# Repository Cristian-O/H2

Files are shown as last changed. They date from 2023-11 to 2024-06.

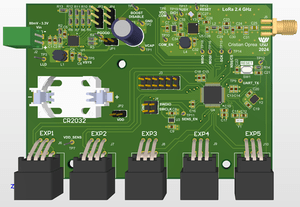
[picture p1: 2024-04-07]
APP/v2/node_design.png

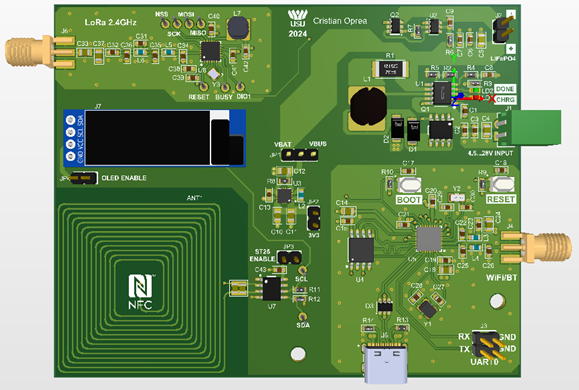
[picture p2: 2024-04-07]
APP/v2/gateway_design.png

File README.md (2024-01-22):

#### 2.4 GHz LoRa Gateway and Node for data aquisition powered by renewable energy

- Node



- Sensor modules
  


- Gateway



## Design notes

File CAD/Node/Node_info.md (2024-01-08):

#Versions
---
## version 1
- [x] SCH_Library
- [x] Schematic
- [ ] PCB_Library
- [ ] Rules
- [ ] Layout
- [ ] Review
- [ ] Enclosure
- [ ] Manufacturing Files
- [ ] Production
> concept version (only schematic)
## version 2
- [x] SCH_Library
- [x] Schematic
- [x] PCB_Library
- [x] Rules
- [x] Layout
- [ ] Review
- [ ] Enclosure
- [ ] Manufacturing Files
- [ ] Production

> *PCB layout and rules for JLCPCB manufacturing added as well as jumpers for current measurement*
Screenshot 2023-11-08 _top
Screenshot 2023-11-08 _bottom
## version 3
- [x] SCH_Library
- [x] Schematic
- [x] PCB_Library
- [x] Rules
- [x] Layout
- [x] Review
- [ ] Enclosure
- [x] Manufacturing Files
- [x] Production
> improved PCB layout, mounting, legends and ADP5091 REG_Dx select jumper (LDO/BOOST enable), calculated capacitors for crystals (16pF), reduced BOM (R and C for reset button)
ready for manufacturing (manufactured in dececmber 2023)
---

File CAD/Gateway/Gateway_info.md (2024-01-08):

#Versions
---
## version 1
- [x] SCH_Library
- [x] Schematic
- [ ] PCB_Library
- [ ] Rules
- [ ] Layout
- [ ] Review
- [ ] Enclosure
- [ ] Manufacturing Files
- [ ] Production
> concept version (only schematic)
## version 2
- [x] SCH_Library
- [x] Schematic
- [x] PCB_Library
- [x] Rules
- [x] Layout
- [ ] Review
- [ ] Enclosure
- [ ] Manufacturing Files
- [ ] Production

> *PCB layout and rules for JLCPCB manufacturing added as well as jumpers for current measurement*



## version 3
- [x] SCH_Library
- [x] Schematic
- [x] PCB_Library
- [x] Rules
- [x] Layout
- [ ] Review
- [ ] Enclosure
- [ ] Manufacturing Files
- [ ] Production
> added legends

## version 4
- [x] SCH_Library
- [x] Schematic
- [x] PCB_Library
- [x] Rules
- [x] Layout
- [x] Review
- [x] Enclosure
- [x] Manufacturing Files
- [x] Production
> modified NOR flash footprint (SOIC-8 208mil), length tuning on tracks
ready for manufacturing (manufactured in december 2023)
---

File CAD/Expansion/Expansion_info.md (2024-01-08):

#Versions
---
## version 1
- [x] SCH_Library
- [x] Schematic
- [x] PCB_Library
- [x] Rules
- [x] Layout
- [ ] Review
- [ ] Manufacturing Files
- [ ] Production
> concept version (only schematic)
## version 2
- [x] SCH_Library
- [x] Schematic
- [x] PCB_Library
- [x] Rules
- [x] Layout
- [ ] Review
- [ ] Manufacturing Files
- [ ] Production
> layout completed




## version 3
- [x] SCH_Library
- [x] Schematic
- [x] PCB_Library
- [x] Rules
- [x] Layout
- [x] Review
- [ ] Manufacturing Files
- [ ] Production
> small improvements
## version 4
- [x] SCH_Library
- [x] Schematic
- [x] PCB_Library
- [x] Rules
- [x] Layout
- [x] Review
- [x] Manufacturing Files
- [x] Production
> ready for production version( manufactured in december 2023)         
---

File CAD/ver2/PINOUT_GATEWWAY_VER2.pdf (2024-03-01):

GPIO

PIN | FUNCTION | CONNECTION
MTCK | MOSI | LoRa
MTDO | MISO | LoRa
MTMS | LoRa_NSS | LoRa
MTDI | SCK | LoRa
U0RXD | UART0_RXD | PROG
U0TXD | UART0_TXD | PROG
GPIO2 | SDA(+FLASH BOOT) | SDA
GPIO3 | DIO1 | LoRa
GPIO8 | SCL(+FLASH BOOT) | SCL
GPIO9 | RESET | LoRa
GPIO10 | BUSY | LoRa
GPIO18 | USB_D_N | PROG
GPIO19 | USB_D_P | PROG

LoRa

MTCK | MOSI | LoRa
MTDO | MISO | LoRa
MTMS | LoRa_NSS | LoRa
MTDI | SCK | LoRa
GPIO3 | DIO1 | LoRa
GPIO9 | RESET(+MCU BOOT) | LoRa
GPIO10 | BUSY | LoRa

PROG

U0RXD | UART0_RXD | PROG
U0TXD | UART0_TXD | PROG
GPIO18 | USB_D_N | PROG
GPIO19 | USB_D_P | PROG

I2C (OLED+ST25DV)

GPIO2 | SDA(+FLASH BOOT) | SDA
GPIO8 | SCL(+FLASH BOOT) | SCL

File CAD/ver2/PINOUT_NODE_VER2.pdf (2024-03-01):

Expansion

PIN | FUNCTION | CONNECTOR
PA4 | ADC12_IN9, DAC1_OUT2 | EXP1
PB10 | I2C2_SCL, TIM2_CH3, USART3_TX, LPUART1_RX | EXP1
PB11 | I2C2_SDA, TIM2_CH4, USART3_RX LPUART1_TX | EXP1
PA0 | ADC1_IN5, WKUP1 | EXP2
PA9 | I2C1_SCL, TIM1_CH2, USART1_TX | EXP2
PA10 | I2C1_SDA, TIM1_CH3, USART1_RX | EXP2
PA1 | ADC1_IN6 | EXP3
PB6 | I2C1_SCL, TIM16_CH1N, USART1_TX | EXP3
PB7 | I2C1_SDA, USART1_RX | EXP3
PA5 | ADC1_IN10, DAC1_OUT2 | EXP4
PB13 | I2C2_SCL, TIM1_CH1N | EXP4
PB14 | I2C2_SDA, TIM15_CH1 | EXP4
PA3 | ADC12_IN7 | EXP5
PB8 | I2C1_SCL, TIM16_CH1 | EXP5
PB9 | I2C1_SDA | EXP5

GPIO-Expansion

PIN | FUNCTION | CONNECTION
PA2 | UART | UART_TX
PA6 | MISO/TX | LoRa
PA7 | MOSI/RX | LoRa
PA8 | COM_EN | LoRa(TPS22919)
PA11 | RESET | LoRa
PA12 | DIO1 | LoRa
PA13 | SWDIO | PROG
PA14 | SWCLK | PROG
PA15 | NSS_CTS | LoRa
PC13 | ADC/NOT_USED | NOT_USED
NRST | RESET+TP12 | PROG
PB0 | BUSY | LoRa
PB1 | BOOST_DISABLE | ADP5091
PB2 | LLD | ADP5091
PB3 | SCK_RTS | LoRa
PB4 | NOT_USED | NOT_USED
PB5 | NOT_USED | NOT_USED
PB12 | NOT_USED | NOT_USED
PB15 | SENS_EN | Sensors(TPS22919)

LoRa

PIN | FUNCTION | CONNECTION
PA6 | MISO/TX | LoRa
PA7 | MOSI/RX | LoRa
PA8 | COM_EN | LoRa(TPS22919)
PA11 | RESET | LoRa
PA12 | DIO1 | LoRa
PA15 | NSS_CTS | LoRa
PB0 | BUSY | LoRa
PB3 | SCK_RTS | LoRa

ADP5091

PB1 | BOOST_DISABLE | ADP5091
PB2 | LLD | ADP5091

PROG+DEBUG

PA13 | SWDIO (SWD) | PROG
PA14 | SWCLK (SWD) | PROG
NRST | RESET(TP12) (SWD HARD RESET) | PROG
PA2 | UART | UART_TX

NOT USED

PC13 | ADC/NOT_USED | NOT_USED
PB4 | NOT_USED | NOT_USED
PB5 | NOT_USED | NOT_USED
PB12 | NOT_USED | NOT_USED

ENABLE

PA8 | COM_EN | LoRa(TPS22919)
PB15 | SENS_EN | Sensors

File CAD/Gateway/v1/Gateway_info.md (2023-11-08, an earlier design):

#Versions
---
## version 1
- [x] SCH_Library
- [x] Schematic
- [ ] Antenna Footprint
- [ ] PCB_Library
- [ ] Rules
- [ ] Layout
- [ ] Modules: Schematic and Layout
- [ ] Review
- [ ] Enclosure
- [ ] Manufacturing Files
- [ ] Production
> concept version (only schematic)
## version 2
- [x] SCH_Library
- [x] Schematic
- [ ] Antenna Footprint
- [ ] PCB_Library
- [ ] Rules
- [ ] Layout
- [ ] Modules: Schematic and Layout
- [ ] Review
- [ ] Enclosure
- [ ] Manufacturing Files
- [ ] Production
---

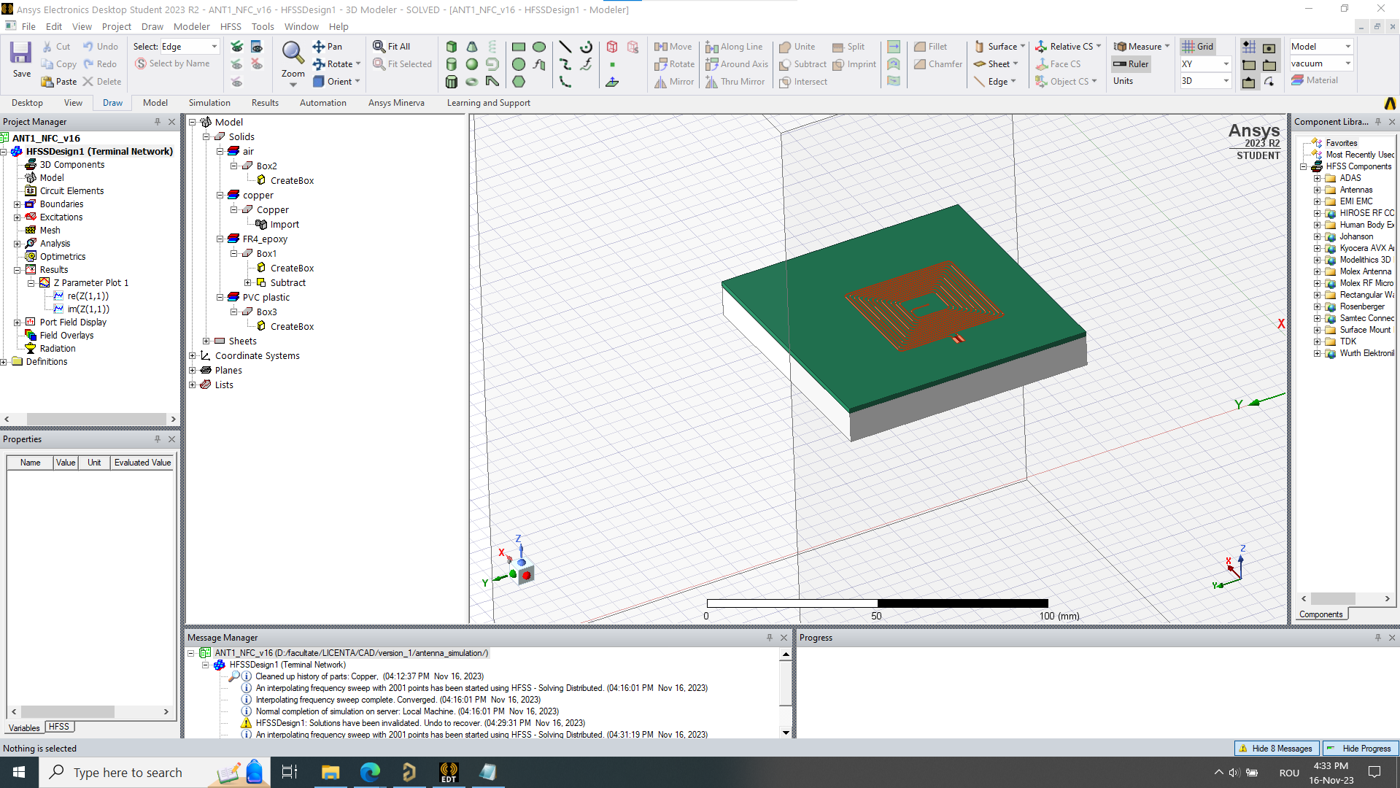
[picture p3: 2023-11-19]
Simulation/NFC_Antenna/ant_v16_design_PVC_10mm.png

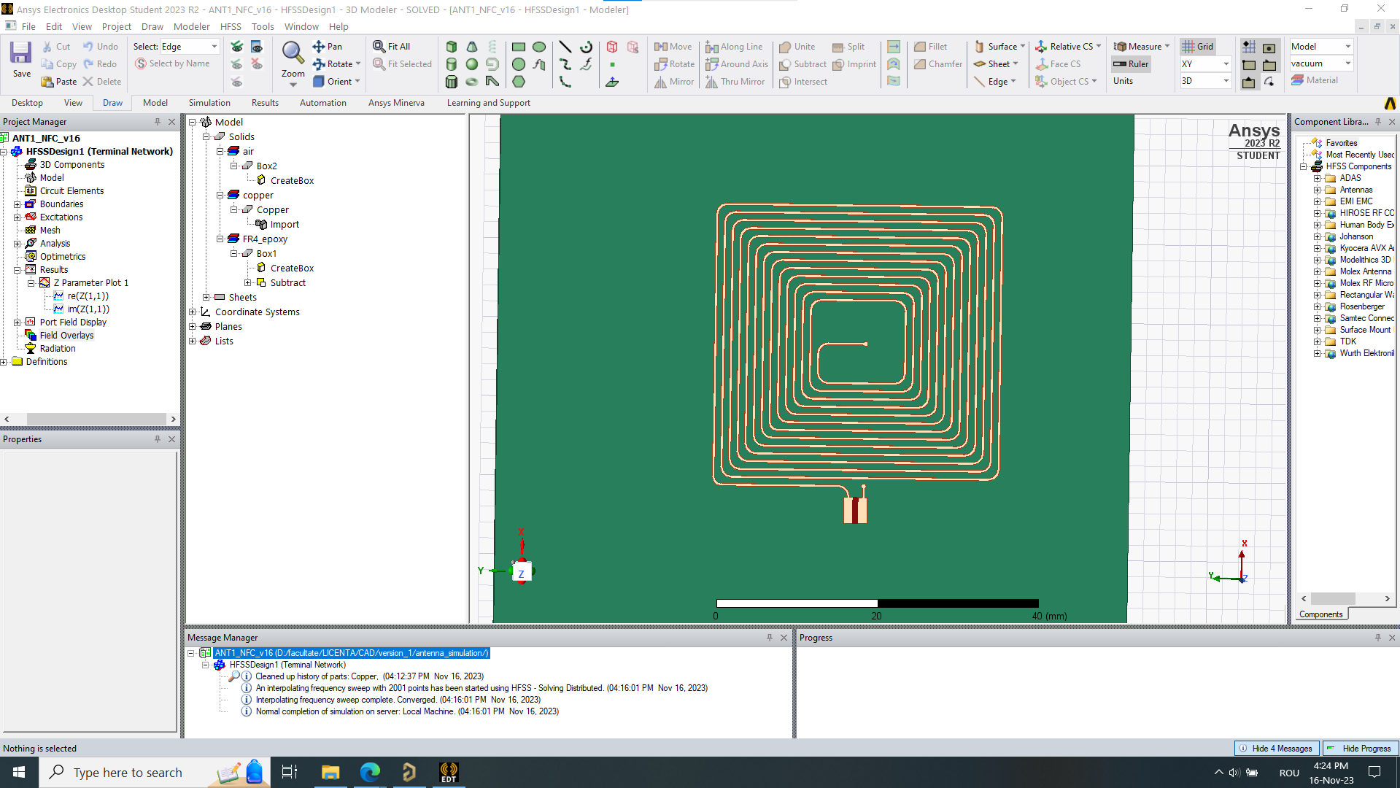
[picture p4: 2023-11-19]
Simulation/NFC_Antenna/ant_v16_design.png

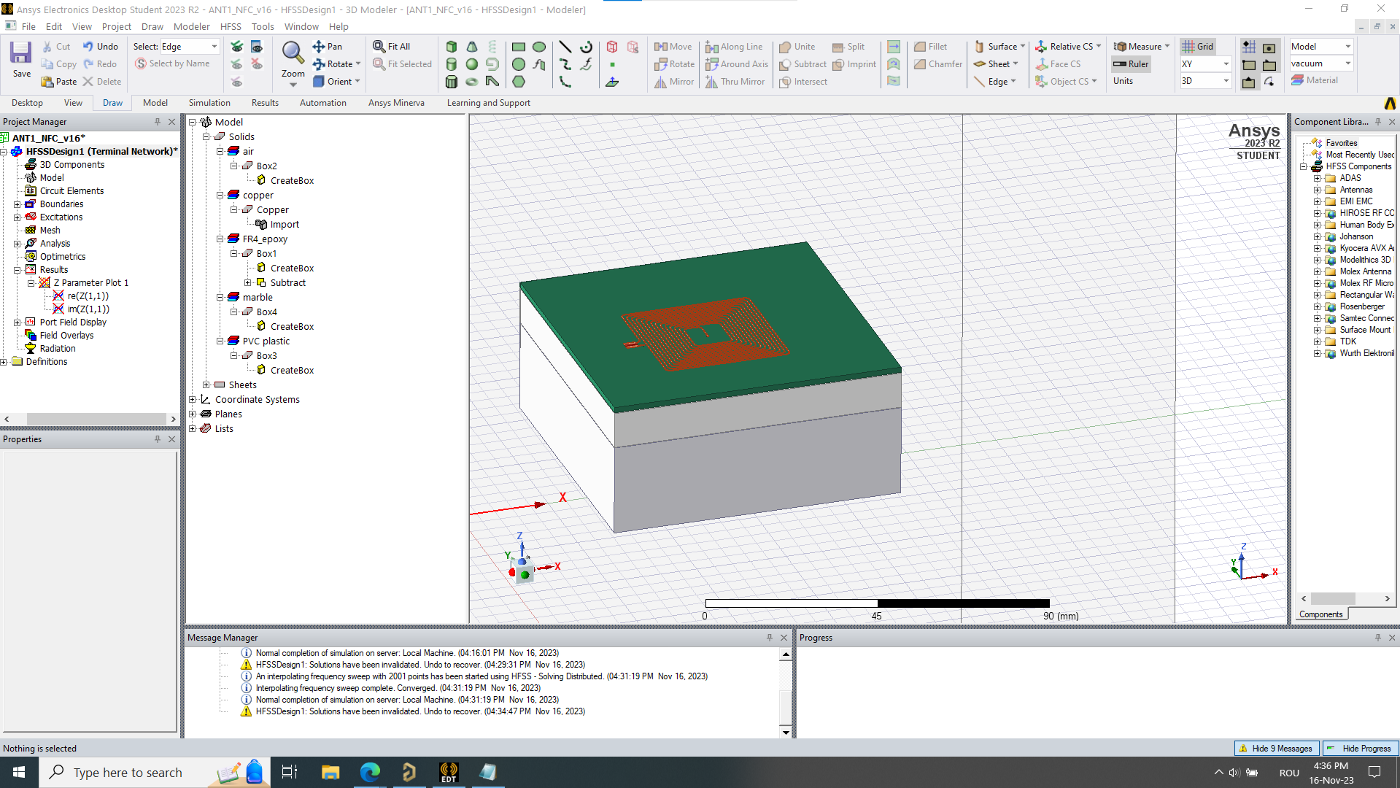
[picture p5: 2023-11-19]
Simulation/NFC_Antenna/ant_v16_design_PVC_10mm_marble_25mm.png

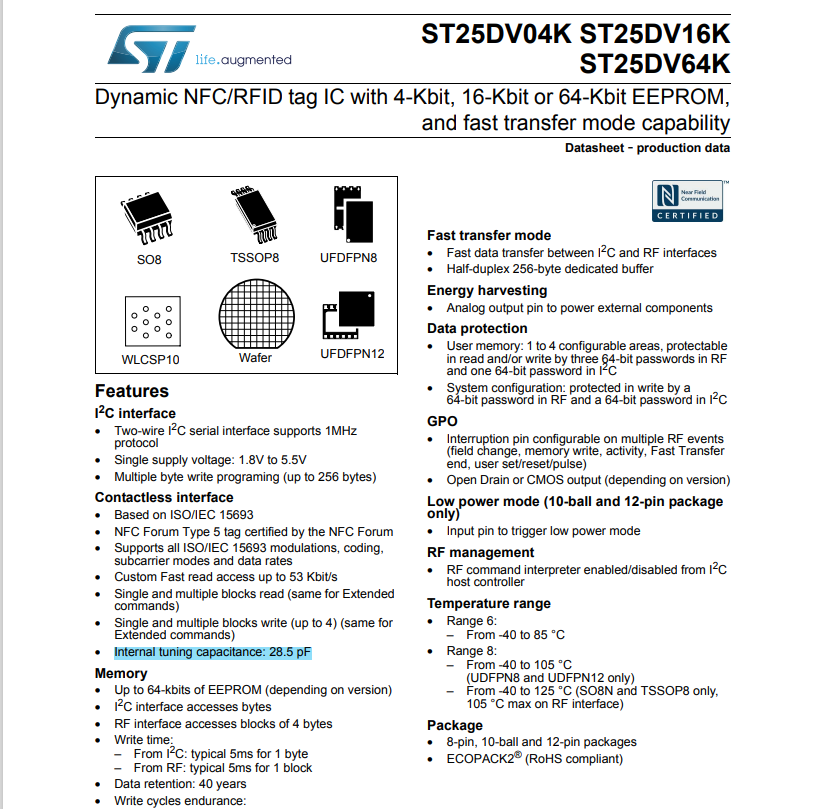
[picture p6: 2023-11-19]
Simulation/NFC_Antenna/ST25DVxx_internal_capacitor.png

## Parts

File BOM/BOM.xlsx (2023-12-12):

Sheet: BOM
PN | Cantitate | Pret | Descriere | Categorie | Total | Subtotal
Condensatori
CL10B104KB8NNNC (https://www.lcsc.com/product-detail/Multilayer-Ceramic-Capacitors-MLCC-SMD-SMT_Samsung-Electro-Mechanics-CL10B104KB8NNNC_C1591.html) | 100 | 0.0025 | 100nF 0603 | Cap | 0.25
CC0603KRX7R9BB103 (https://www.lcsc.com/product-detail/Multilayer-Ceramic-Capacitors-MLCC-SMD-SMT_YAGEO-CC0603KRX7R9BB103_C100042.html) | 100 | 0.002 | 10nF 0603 | Cap | 0.2
CL10A106MP8NNNC (https://www.lcsc.com/product-detail/Multilayer-Ceramic-Capacitors-MLCC-SMD-SMT_Samsung-Electro-Mechanics-CL10A106MP8NNNC_C85713.html) | 100 | 0.0054 | 10uF 0603 | Cap | 0.54
CL21A106KAYNNNE (https://www.lcsc.com/product-detail/Multilayer-Ceramic-Capacitors-MLCC-SMD-SMT_Samsung-Electro-Mechanics-CL21A106KAYNNNE_C15850.html) | 50 | 0.0105 | 10uF 0805 | Cap | 0.525
CL10A475KA8NQNC (https://www.lcsc.com/product-detail/Multilayer-Ceramic-Capacitors-MLCC-SMD-SMT_Samsung-Electro-Mechanics-CL10A475KA8NQNC_C69335.html) | 50 | 0.0145 | 4.7uF 0603 | Cap | 0.725
CL10A105KO8NNNC (https://www.lcsc.com/product-detail/Multilayer-Ceramic-Capacitors-MLCC-SMD-SMT_Samsung-Electro-Mechanics-CL10A105KO8NNNC_C1592.html) | 100 | 0.0031 | 1uF 0603 | Cap | 0.31
0603CG1R2C500NT (https://www.lcsc.com/product-detail/Multilayer-Ceramic-Capacitors-MLCC-SMD-SMT_FH-Guangdong-Fenghua-Advanced-Tech-0603CG1R2C500NT_C1638.html) | 100 | 0.0029 | 1.2pF 0603 | Cap | 0.29
TCC0603X5R474M250CT (https://www.lcsc.com/product-detail/Multilayer-Ceramic-Capacitors-MLCC-SMD-SMT_CCTC-TCC0603X5R474M250CT_C18185762.html) | 100 | 0.0038 | 470nF 0603 | Cap | 0.38
FCC0603N0R5C500CT (https://www.lcsc.com/product-detail/Multilayer-Ceramic-Capacitors-MLCC-SMD-SMT_FOJAN-FCC0603N0R5C500CT_C5137584.html) | 100 | 0.0031 | 0.5pF 0603 | Cap | 0.31
CL10C101JB8NNNC (https://www.lcsc.com/product-detail/Multilayer-Ceramic-Capacitors-MLCC-SMD-SMT_Samsung-Electro-Mechanics-CL10C101JB8NNNC_C14858.html) | 100 | 0.0027 | 100pF 0603 | Cap | 0.27
0603CG0R8C500NT (https://www.lcsc.com/product-detail/Multilayer-Ceramic-Capacitors-MLCC-SMD-SMT_FH-Guangdong-Fenghua-Advanced-Tech-0603CG0R8C500NT_C501845.html) | 100 | 0.003 | 0.8pF 0603 | Cap | 0.3
CL10B224KA8NNNC (https://www.lcsc.com/product-detail/Multilayer-Ceramic-Capacitors-MLCC-SMD-SMT_Samsung-Electro-Mechanics-CL10B224KA8NNNC_C21120.html) | 100 | 0.0057 | 220nF 0603 | Cap | 0.57
0603CG3R3C500NT (https://www.lcsc.com/product-detail/Multilayer-Ceramic-Capacitors-MLCC-SMD-SMT_FH-Guangdong-Fenghua-Advanced-Tech-0603CG3R3C500NT_C1660.html) | 100 | 0.0027 | 3.3pF 0603 | Cap | 0.27
0603CG160J500NT (https://www.lcsc.com/product-detail/Multilayer-Ceramic-Capacitors-MLCC-SMD-SMT_FH-Guangdong-Fenghua-Advanced-Tech-0603CG160J500NT_C1646.html) | 100 | 0.0039 | 16pF, C0G, 0603 | Cap | 0.39
 |  |  |  |  |  | 5.33
Rezistori
RS-03K5101FT (https://www.lcsc.com/product-detail/Chip-Resistor-Surface-Mount_FH-Guangdong-Fenghua-Advanced-Tech-RS-03K5101FT_C156350.html) | 100 | 0.001 | 5.1k 0603 | Rez | 0.1
RC0603FR-071K5L (https://www.lcsc.com/product-detail/Chip-Resistor-Surface-Mount_YAGEO-RC0603FR-071K5L_C114668.html) | 100 | 0.0012 | 1.5k 0603 | Rez | 0.12
0603WAF1000T5E (https://www.lcsc.com/product-detail/Chip-Resistor-Surface-Mount_UNI-ROYAL-Uniroyal-Elec-0603WAF1000T5E_C22775.html) | 100 | 0.001 | 100R 0603 | Rez | 0.1
PT2512FK-7W0R25L (https://www.lcsc.com/product-detail/Chip-Resistor-Surface-Mount_YAGEO-PT2512FK-7W0R25L_C875877.html) | 5 | 0.1434 | 250mR 2512 | Rez | 0.717
FRC0603F1200TS (https://www.lcsc.com/product-detail/Chip-Resistor-Surface-Mount_FOJAN-FRC0603F1200TS_C2906988.html) | 100 | 0.0009 | 120R 0603 | Rez | 0.09
SCR0603F27K (https://www.lcsc.com/product-detail/Chip-Resistor-Surface-Mount_VO-SCR0603F27K_C3016359.html) | 100 | 0.0009 | 27k 0603 | Rez | 0.09
RTT033001FTP (https://www.lcsc.com/product-detail/Chip-Resistor-Surface-Mount_RALEC-RTT033001FTP_C103514.html) | 100 | 0.0008 | 3k 0603 | Rez | 0.08
RS-03K2001FT (https://www.lcsc.com/product-detail/Chip-Resistor-Surface-Mount_FH-Guangdong-Fenghua-Advanced-Tech-RS-03K2001FT_C115336.html) | 100 | 0.001 | 2k 0603 | Rez | 0.1
WR04W6044FTL (https://www.lcsc.com/product-detail/Chip-Resistor-Surface-Mount_Walsin-Tech-Corp-WR04W6044FTL_C172106.html) | 50 | 0.0012 | 6.04M 0402 (nu e 0603) | Rez | 0.06
RC0603FR-074M7L (https://www.lcsc.com/product-detail/Chip-Resistor-Surface-Mount_YAGEO-RC0603FR-074M7L_C123423.html) | 100 | 0.0012 | 4.7M 0603 | Rez | 0.12
SCR0603J18M (https://www.lcsc.com/product-detail/Chip-Resistor-Surface-Mount_VO-SCR0603J18M_C3017646.html) | 100 | 0.0013 | 18M 0603 | Rez | 0.13
FRC0603F2213TS (https://www.lcsc.com/product-detail/Chip-Resistor-Surface-Mount_FOJAN-FRC0603F2213TS_C7467463.html) | 100 | 0.0008 | 221kR 0603 | Rez | 0.08
RC0603FR-07150KL (https://www.lcsc.com/product-detail/Chip-Resistor-Surface-Mount_YAGEO-RC0603FR-07150KL_C114660.html) | 100 | 0.0012 | 150k 0603 | Rez | 0.12
WR06X4701FTL (https://www.lcsc.com/product-detail/Chip-Resistor-Surface-Mount_Walsin-Tech-Corp-WR06X4701FTL_C163914.html) | 100 | 0.0009 | 4.7k 0603 | Rez | 0.09
RC0402FR-075M9L (https://www.lcsc.com/product-detail/Chip-Resistor-Surface-Mount_YAGEO-RC0402FR-075M9L_C477757.html) | 100 | 0.0007 | 5.9M 0603 | Rez | 0.07
WR06W4124FTL (https://www.lcsc.com/product-detail/Chip-Resistor-Surface-Mount_Walsin-Tech-Corp-WR06W4124FTL_C367755.html) | 100 | 0.0017 | 4.12M 0603 | Rez | 0.17
RC0402FR-075M49L (https://www.lcsc.com/product-detail/Chip-Resistor-Surface-Mount_YAGEO-RC0402FR-075M49L_C477751.html) | 100 | 0.0007 | 5.49M 0402 | Rez | 0.07
RC0603FR-074M53L (https://www.lcsc.com/product-detail/Chip-Resistor-Surface-Mount_YAGEO-RC0603FR-074M53L_C482860.html) | 100 | 0.0012 | 4.53M 0603 | Rez | 0.12
RC0402FR-073M92L (https://www.lcsc.com/product-detail/Chip-Resistor-Surface-Mount_YAGEO-RC0402FR-073M92L_C477709.html) | 100 | 0.001 | 3.92M 0402 | Rez | 0.1
WR06X1003FTL (https://www.lcsc.com/product-detail/Chip-Resistor-Surface-Mount_Walsin-Tech-Corp-WR06X1003FTL_C132374.html) | 100 | 0.0009 | 100k 0603 | Rez | 0.09
RC0603FR-0733K2L (https://www.lcsc.com/product-detail/Chip-Resistor-Surface-Mount_YAGEO-RC0603FR-0733K2L_C185338.html) | 100 | 0.0012 | 33.2k 0603 | Rez | 0.12
 |  |  |  |  |  | 2.737
Bobine
XRCD75-470M (https://www.lcsc.com/product-detail/Power-Inductors_XR-XRCD75-470M_C5289449.html) | 5 | 0.0689 | 47uH, 5x7 | Bobine | 0.3445
CPY160808T-2R2M-NP (https://www.lcsc.com/product-detail/Inductors-SMD_Chilisin-Elec-CPY160808T-2R2M-NP_C365953.html) | 20 | 0.0138 | 2,2uH, 0603 | Bobine | 0.276
SDCL1608C2N4STDF (https://www.lcsc.com/product-detail/Inductors-SMD_Sunlord-SDCL1608C2N4STDF_C370235.html) | 50 | 0.0084 | 2,4nH, 0603 | Bobine | 0.42
VHF160808H3N0ST (https://www.lcsc.com/product-detail/Inductors-SMD_FH-Guangdong-Fenghua-Advanced-Tech-VHF160808H3N0ST_C395085.html) | 100 | 0.0054 | 3nH, 0603 | Bobine | 0.54 |  | 2.5 nu e in stoc => 2.4 utilizat
XRCD43-220M (https://www.lcsc.com/product-detail/Power-Inductors_span-style-background-color-ff0-XR-span-XRCD43-220M_C5289404.html) | 20 | 0.0266 | 22uH, 4x3.2 | Bobine | 0.532
XRCD43-150M (https://www.lcsc.com/product-detail/Power-Inductors_span-style-background-color-ff0-XR-span-XRCD43-150M_C5289403.html) | 20 | 0.0266 | 15uH, 4x3.2 | Bobine | 0.532
VHF160808H2N2ST (https://www.lcsc.com/product-detail/Inductors-SMD_FH-Guangdong-Fenghua-Advanced-Tech-VHF160808H2N2ST_C1028.html) | 100 | 0.0055 | 2.2nH 0603 | Bobine | 0.55
CH1608H6N8J(f) (https://www.lcsc.com/product-detail/Inductors-SMD_CEC-Shenzhen-Zhenhua-Fu-Elec-CH1608H6N8J-f_C316305.html) | 100 | 0.0036 | 6,8nH 0603 | Bobine | 0.36 | 3.1945
Diode
SS34-MS (https://www.lcsc.com/product-detail/Schottky-Barrier-Diodes-SBD_MSKSEMI-SS34-MS_C2836396.html) | 20 | 0.0196 | Dioda putere | Dioda | 0.392
USBLC6-2SC6 (https://www.lcsc.com/product-detail/ESD-Protection-Devices_UMW-Youtai-Semiconductor-Co-Ltd-USBLC6-2SC6_C2687116.html) | 10 | 0.0341 | ESD USB | Diode ESD | 0.341
XL-1608SURC-06 (https://www.lcsc.com/product-detail/Light-Emitting-Diodes-LED_XINGLIGHT-XL-1608SURC-06_C965799.html) | 100 | 0.0026 | LED 0603 rosu | LED | 0.26
XL-1608SYGC-06 (https://www.lcsc.com/product-detail/Light-Emitting-Diodes-LED_XINGLIGHT-XL-1608SYGC-06_C965805.html) | 100 | 0.0048 | LED 0603 verde | LED | 0.48
 |  |  |  |  |  | 1.473
Cristale cuart
01.X.TG.11CJJRI000327680 (https://www.lcsc.com/product-detail/Crystals_CREC-01-X-TG-11CJJRI000327680_C7570522.html) | 5 | 0.1184 | 32.768kHz, 12.5pF, 3215x2 | Cristal | 0.592
X32258MOB4SI (https://www.lcsc.com/product-detail/Crystals_YXC-X32258MOB4SI_C2682775.html) | 5 | 0.1387 | 8MHz, 12pF, 3225x4 | Cristal | 0.6935
S3240000121040 (https://www.lcsc.com/product-detail/Crystals_JGHC-S3240000121040_C426989.html) | 10 | 0.048 | 40MHz, 12pF,3225x4 | Cristal | 0.48
XC21M4-52.000-F10NNHPL (https://www.lcsc.com/product-detail/Crystals_HCI-XC21M4-52-000-F10NNHPL_C3034316.html) | 5 | 0.1224 | 52MHz, 10pF | Cristal | 0.612
 |  |  |  |  |  | 2.3775
Circuite Integrate
SX1280IMLTRT (https://www.lcsc.com/product-detail/RF-Transceiver-ICs_SEMTECH-SX1280IMLTRT_C125969.html) | 3 | 4.7489 | 2.4 GHz LoRa |  | 14.2467
STM32L431CCT6 (https://www.lcsc.com/product-detail/Microcontroller-Units-MCUs-MPUs-SOCs_STMicroelectronics-STM32L431CCT6_C486681.html) | 2 | 1.8741 | STM32L431, 256 kB, LQFP-48 |  | 3.7482
ADP5091ACPZ-2-R7 (https://www.lcsc.com/product-detail/Battery-Management-ICs_Analog-Devices-ADP5091ACPZ-2-R7_C579259.html) | 2 | 5.1801 | ADP5091, low power energy harvester |  | 10.3602
TPS22919DCKR (https://www.lcsc.com/product-detail/Power-Distribution-Switches_Texas-Instruments-TPS22919DCKR_C2149796.html) | 4 | 0.3389 | power distribution switch |  | 1.3556
CN3801 (https://www.lcsc.com/product-detail/Battery-Management-ICs_ShangHai-Consonance-Elec-CN3801_C840499.html) | 2 | 0.5091 | incarcator LiFePO4 |  | 1.0182
HY2112-BB (https://www.lcsc.com/product-detail/Battery-Management-ICs_HYCON-Tech-HY2112-BB_C161942.html) | 5 | 0.1005 | LiFePO4 protectie |  | 0.5025
ST25DV04K-IER6S3 (https://www.lcsc.com/product-detail/RF-Chips_STMicroelectronics-ST25DV04K-IER6S3_C155601.html) | 3 | 0.3675 | NFC |  | 1.1025
ESP32-C3 (https://www.lcsc.com/product-detail/Microcontroller-Units-MCUs-MPUs-SOCs_Espressif-Systems-ESP32-C3_C2838500.html) | 2 | 1.3539 | uC |  | 2.7078
TPS63000DRCR (https://www.lcsc.com/product-detail/DC-DC-Converters_Texas-Instruments-TPS63000DRCR_C24966.html) | 2 | 0.8846 | DC-DC buck boost |  | 1.7692
W25Q32JVSSIQ (https://www.lcsc.com/product-detail/NOR-FLASH_Winbond-Elec-W25Q32JVSSIQ_C82344.html) | 5 | 0.2616 | NOR flash |  | 1.308
FDS4435BZ(UMW) (https://www.lcsc.com/product-detail/MOSFETs_UMW-Youtai-Semiconductor-Co-Ltd-FDS4435BZ-UMW_C7503191.html) | 5 | 0.1528 | MOS protectie |  | 0.764
FS8205A (https://www.lcsc.com/product-detail/MOSFETs_FUXINSEMI-FS8205A_C908265.html) | 10 | 0.0569 | MOS protectie |  | 0.569
LPV521MGX/NOPB (https://www.lcsc.com/product-detail/Operational-Amplifier_Texas-Instruments-LPV521MGX-NOPB_C779403.html) | 4 | 0.7 | OPAMP |  | 2.8
REF3020AIDBZR (https://www.lcsc.com/product-detail/Voltage-References_Texas-Instruments-REF3020AIDBZR_C26804.html) | 2 | 0.4853 | 2.048V reference series |  | 0.9706
ENS210-LQFM (https://www.lcsc.com/product-detail/Temperature-and-Humidity-Sensor_AMS-ENS210-LQFM_C2991202.html) | 2 | 1.1519 | Temp+Umid |  | 2.3038
LTR-390UV-01 (https://www.lcsc.com/product-detail/Ambient-Light-Sensors_Lite-On-LTR-390UV-01_C492374.html) | 2 | 0.9594 | UV+Nivel Lumina |  | 1.9188
 |  |  |  |  |  | 47.4451
Conectori
12251140CNG0S115001 (https://www.lcsc.com/product-detail/Pin-Headers_JILN-12251140CNG0S115001_C429959.html) | 5 | 0.0962 | 2.54, 40p, drept | Header | 0.481
KH-2.54TXM-BK-6.5H-R (https://www.lcsc.com/product-detail/Shunts-Jumpers_Shenzhen-Kinghelm-Elec-KH-2-54TXM-BK-6-5H-R_C5274540.html) | 50 | 0.0081 | 2.54, inchis, rosu | Jumper | 0.405
M254D-02-065-B (https://www.lcsc.com/product-detail/Shunts-Jumpers_DEALON-M254D-02-065-B_C2998928.html) | 50 | 0.0069 | 2.54, inchis, negru | Jumper | 0.345
ER06BGFBK (https://www.lcsc.com/product-detail/Card-Edge-Connectors_WingTAT-ER06BGFBK_C5173325.html) | 10 | 0.288 | 2,54, 6P, card edge | Conector | 2.88
SKRPACE010 (https://www.lcsc.com/product-detail/Tactile-Switches_ALPSALPINE-SKRPACE010_C139797.html) | 10 | 0.053 | tactile switch, RESET | Buton | 0.53
CR2032-BS-6-1 (https://www.lcsc.com/product-detail/Battery-Connectors_Q-J-CR2032-BS-6-1_C70377.html) | 5 | 0.1559 | CR2032 suport | Conector baterie | 0.7795
BWSMA-KE-P001 (https://www.lcsc.com/product-detail/RF-Connectors-Coaxial-Connectors_BAT-WIRELESS-BWSMA-KE-P001_C496550.html) | 5 | 0.3453 | SMA edge mount | Conector RF | 1.7265
DB2ERC-2.54-2P-GN (https://www.lcsc.com/product-detail/Pluggable-System-Terminal-Block_DORABO-DB2ERC-2-54-2P-GN_C2927503.html) | 5 | 0.073 | Plugin terminal 90* PCB | Conector | 0.365
DB2EK-2.54-2P-GN-S (https://www.lcsc.com/product-detail/Pluggable-System-Terminal-Block_DORABO-DB2EK-2-54-2P-GN-S_C2927483.html) | 5 | 0.3002 | Plugin terminal cablu | Conector | 1.501
TYPE-C 16PIN 2MD(073) (https://www.lcsc.com/product-detail/USB-Connectors_SHOU-HAN-TYPE-C-16PIN-2MD-073_C2765186.html) | 5 | 0.0524 | USB-C | Conector | 0.262
TF-115-BCP9 (https://www.lcsc.com/product-detail/SD-Card-Connectors_XUNPU-TF-115-BCP9_C720505.html) | 5 | 0.074 | uSD card | Conector | 0.37
KH-BNC50-3511 (https://www.lcsc.com/product-detail/RF-Connectors-Coaxial-Connectors_Shenzhen-Kinghelm-Elec-KH-BNC50-3511_C2837587.html) | 1 | 0.6619 | BNC | Conector | 0.6619
MX127-5.0-03P-GN01-Cu-Y-A (https://www.lcsc.com/product-detail/Screw-terminal_MAX-MX127-5-0-03P-GN01-Cu-Y-A_C5188441.html) | 5 | 0.1543 | Terminal Surub 5mm | Conector | 0.7715
 |  |  |  |  |  | 11.0784
 |  |  |  |  | 73.9955

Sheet: Misc
PN | Cantitate | Pret | Descriere | Total
BW2.4JWX105-7KJ (https://www.lcsc.com/product-detail/Antennas_BAT-WIRELESS-BW2-4JWX105-7KJ_C497017.html) | 3 | 1.1087 | Antena 2.4 GHz pentru WiFi sau LoRa | 3.3261
KH-SMA-K513-11G (https://www.lcsc.com/product-detail/RF-Connectors-Coaxial-Connectors_Shenzhen-Kinghelm-Elec-KH-SMA-K513-11G_C530660.html) | 4 | 0.5091 | Conector SMA cu surub pentru antena | 2.0364
DOSIN-811-0211A (https://www.lcsc.com/product-detail/Radio-Frequency-Cable_dosinconn-DOSIN-811-0211A_C3018934.html) | 2 | 2.17 | Cablu SMA la SMA | 4.34
 |  |  |  | 9.7025
 |  |  |  | 83.698

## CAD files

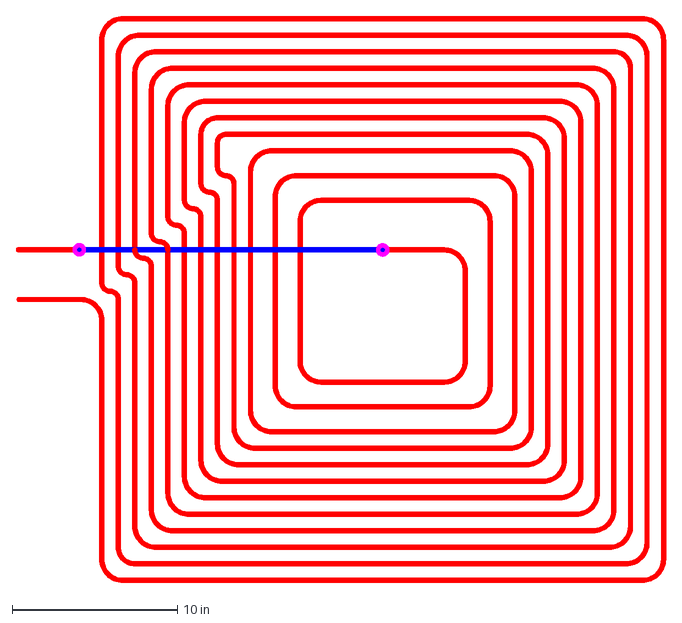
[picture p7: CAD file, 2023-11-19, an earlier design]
Simulation/NFC_Antenna/ANT1_NFC_v3_dxf.DXF
39.3 x 34.3 in

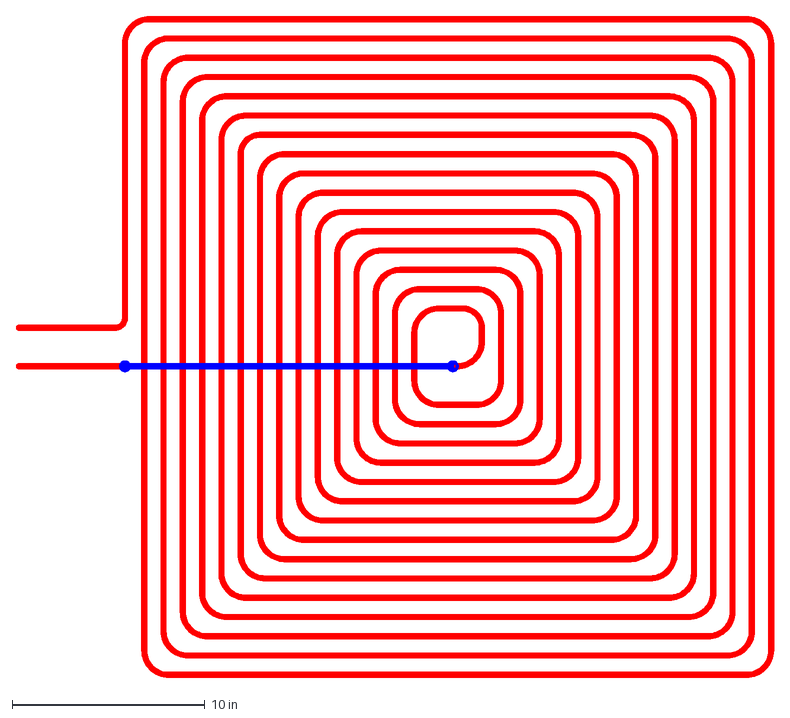
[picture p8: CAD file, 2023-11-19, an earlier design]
Simulation/NFC_Antenna/ANT1_NFC_v6_dxf.DXF
39.3 x 34.3 in

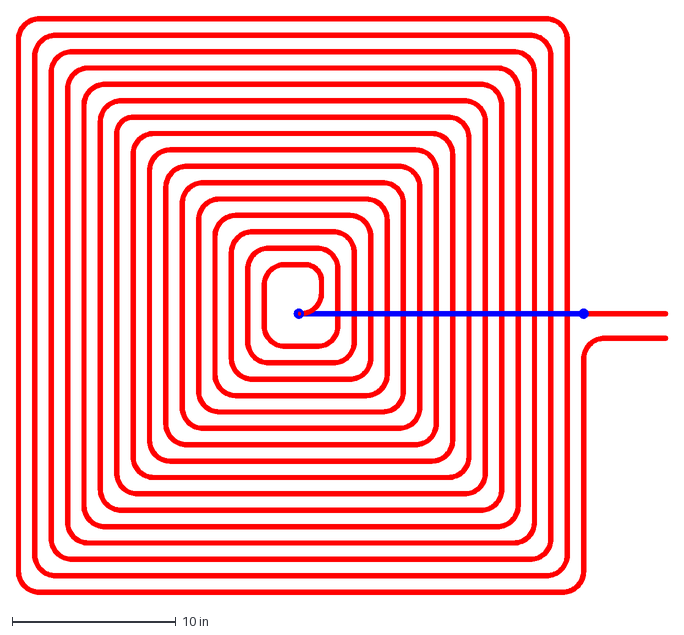
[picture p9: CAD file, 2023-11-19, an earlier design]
Simulation/NFC_Antenna/ANT1_NFC_v8_dxf.DXF
39.8 x 35.3 in

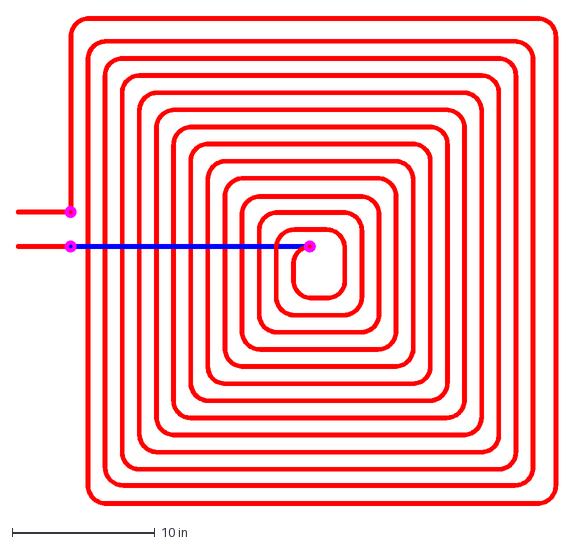
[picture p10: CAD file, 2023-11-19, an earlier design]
Simulation/NFC_Antenna/ANT1_NFC_v1_dxf.DXF
38.0 x 34.3 in

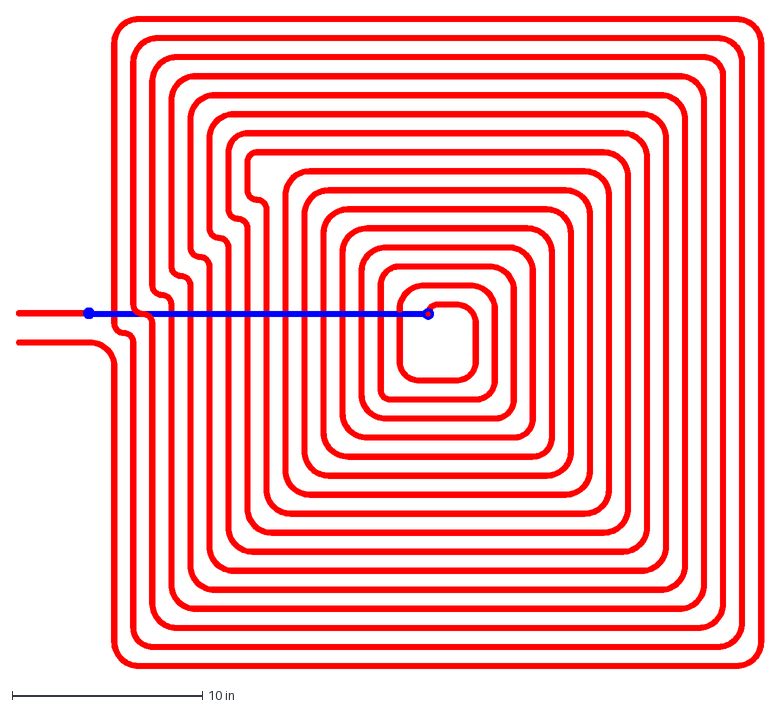
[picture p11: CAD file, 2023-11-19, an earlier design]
Simulation/NFC_Antenna/ANT1_NFC_v4_dxf.DXF
39.3 x 34.3 in

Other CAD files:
Simulation/NFC_Antenna/ANT1_NFC_v16_dxf.DXF
Simulation/NFC_Antenna/ANT1_NFC_v10_dxf.DXF
Simulation/NFC_Antenna/ANT1_NFC_v9_dxf.DXF
Simulation/NFC_Antenna/ANT1_NFC_v13_dxf.DXF
Simulation/NFC_Antenna/ANT1_NFC_v12_dxf.DXF
Simulation/NFC_Antenna/ANT1_NFC_v11_dxf.DXF
Simulation/NFC_Antenna/ANT1_NFC_v14_dxf.DXF
Simulation/NFC_Antenna/ANT1_NFC_v15_dxf.DXF
Simulation/NFC_Antenna/ANT1_NFC_v7_dxf.DXF
Simulation/NFC_Antenna/ANT1_NFC_v5_dxf.DXF

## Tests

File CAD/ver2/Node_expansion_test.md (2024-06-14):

Tested
- [x] Supercapacitor charging and management (ADP5091)
- [x] STM32L431 
- [x] Lora (SX1280)
      
- [x] ENS210 (Temp+Humidity)
- [x] LTR-390-UV (Light intensity & UV)(tested in both UVS and ALS, precise, fast)
- [x] DS18-B20 (Surface temperature)(working, not very precise at 2.9V but variation of temperature is working)
- [x] Analog PH (PH of water)
      
Working/(Needs improvement)
- [X] Supercapacitor charging and management (ADP5091):




      Charging to 3.89V and discharge to 2.24V, reg_out (set to 3V, 3.05V real value), charging over 0.5V on VIN
      Charging at down to 0.5V tested and working, hard to make note of as charging is very slow.
      Reg_Out will give 3V only in LDO mode (buck and LDO work only for Supercap. charging)
      Reg_Out voltge is controlled only by VID resistor (should give 2.5V when it is not populated) -Reg_out is working properly
      REG_D1 and REG_D2 controls mode of operation (now is connected with either PGOOD or GND -for LDO or VIN Hybrid Mode, JUMPER for VDD should be connected)
      Hybrid mode make the use of direct supply from Vin to LDO (Supercapacitor voltage will decrease slowly, prolonging it's life), charging is slower(more inefficient as suggested by the datasheet and forum posts)
      
      IMPROVEMENTS> VDD=REG_OUT (3V) not VSYS(2.2 to 3.8V), TEST point for SUPERCAPCAP voltage measurement and VSYS(can be used for safe discharge of the supercapacitor)
      LLD is not very usefull(MINOP comparator is not working as intended)
      Fully charged in 1.5h with solar pannel at 0.95V (from 2.5V to 3.89V). Backup Tested (CR2032-3.32V fully charged at VSYS output when SCAP is disconnected)
      Fully tested and functional!!!
- [x] STM32L431(working)
      Fully tested and functional!!!
- [x] Lora(registers were read, ~200 packets sent without errors during a single full charge of the supercapacitor)
      regs_read_node_lora
      

      Fully tested and functional!!!

>Sensors
- [x] ENS210 (Temp+Humidity)(both working, tested in ArduinoIDE using STM32Duino and Wire, SoftwareSerial for UART2 transmission)
- [x] LTR-390-UV (Light intensity & UV)(tested in both UVS and ALS, precise, fast-up to 20bits of resolution -could be used to determine weather or not energi is produced from solar)
- [x] DS18-B20 (Surface temperature)(working, not very precise at 2.9V but variation of temperature is working)
- [x] Analog PH (PH of water)(variation of ph is noticeable, high current consumption-20mA because of the voltage reference, might not be very usefull)
- [x] HALL sensor (for readout of a mechanical trigger/ level)

Parameters> TEMP+HUMID,UV/ALS,TEMP_P,HALL,VBAT,LLD?

To Do(Software)
- [x] Multiple Wire interfaces (At least two> I2C1 and ISC2)
- [x] Multiple sensor read
- [x] Packet for LoRa transmission (with all sensor values)
- [x] Sleep implementation(less than 1uA in sleep)
- [x] Block/flow diagram of the code(working...)
- [x] Field testing (working time, power consumption)-one day tested on both=> working (less than 1uA in sleep=> should be ~800nA and less than 20mA on data sending
- [x] Range testing (distance) >600m with SF7 tested(line of sight)

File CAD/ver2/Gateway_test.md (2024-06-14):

Tested
- [x] Battery charge (LiFePO4)
- [x] Buck-boost (TPS63000 replaced with TPS63001-3.3V version)
- [x] ESP32-C3
- [x] NFC
- [x] LoRa
- [x] OLED(SSD1306, 128x32)

Working/(Needs improvement)
- [x] Battery charge (LiFePO4, charging is working :MPPT is set to 6V for the used solar pannel)
      
      Current vs Time (end of charge; LiFePO4 cell voltage = 3 4V)
      

      Fully functional charging the cell from 3.3v to 3.4V (~300mA capacity); Vin=6V, MPPT=6V, Max current=350mA). Reverse battery tested (Q2 was smoking, no components were harmed, Q2 will act as fuse during reverse-battery -one body diode of the internal MOS transistor will burn). Fully tested during the start of April
- [x] Buck-boost (TPS63001)(tested on VBUS-5V and VBAT-3.2V)
- [x] ESP32-C3 (boot configuration causes problems- GPIO2,9 and 8 should be configured for flashing-pull up and capacitor on GPIO9(RC for timing), WiFi is Working, reset, USB-CDC flash and debug + serial=> solved by correct button connection and 470nF + 5.1k resistors for the ENABLE and BOOT timing during startup instead of 100nF)
      PICT0013
      chip_id_esp32
      wifi_test_esp32_c3_1

- [x] NFC (Antenna is working. Detected by ST25DV android app at ~2 to 4cm distance, I2C tested-1,2,3,4 wrote from phone read by ESP32, 0,0,0,0 read by phone after write from ESP32; UID read by esp32)
     Screenshot_20240119_225934_com st st25nfc
     st25dv04k_UID
     st25dv04k_read0x0_1234

- [x] LoRa (Regs could be read, data can be read and stored in RECEIVE_BUFFER, RSSI is read, tested at SF7, power of 10dB, ~800 packets read without errors)
       LoRa_1
       LoRa_2
       

- [x] OLED (SSD1306,128x32) tested with Adafruit_SSD1306 and U8g2 libraries (Meditation error when LoRa and OLED are used, I2C scan is working, devices are detected on I2C)
      

To Do(Software)
- [x] FireBase and Thingspeak write + WiFi connection
- [x] OLED working as well as LoRa (mainly for range testing)
- [x] ST25DV take SSID and PASSWORD for the AP (read before Wi-Fi connect)
- [x] Sleep during no data reception (ex: 25 min sleep 5 min wakeup)-WiFi is OFF=> no sleep in order to receive data(~30mA in this state)
- [x] Block/Flow diagram for the software part (CLOUD integration, Sleep/LoRa/ST25)-working...
      
To Do(Hardware)
- [x] 18650 Holder/wall mount/antenna holder
- [x] Field Testing (Battery Life, Range)>1d each without charging

Other
- [x] App description
- [x] Testing and results in documentation
- [x] Pictures in documentation (complete documentation until last FW versions)

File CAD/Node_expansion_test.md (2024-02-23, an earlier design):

Tested
- [x] Supercapacitor charging and management (ADP5091)
- [x] STM32L431 
- [ ] Lora (SX1280)
      
>Sensors (EXP headers are ordered wrong EXP3 has EXP1 pins)
- [x] ENS210 (Temp+Humidity)
- [x] LTR-390-UV (Light intensity & UV)(tested in both UVS and ALS, precise, fast)
- [x] DS18-B20 (Surface temperature)(working, not very precise at 2.9V but variation of temperature is working)
- [ ] Analog PH (PH of water)
      
Working/(Needs improvement)
- [X] Supercapacitor charging and management (ADP5091):




      Charging to 3.86V and discharge to 2.24V, no reg_out (unstable, <2V, set to 3V), charging over 3V on VIN
      Charging at down to 0.5V tested (working only when CBP capacitor is touched (this can be due to high ESR of CBP capacitor or that it is not soldered properly) => resoldered then replaced with another => same behavior => CBP should be reordered with lower ESR or PCB redesign without nearby copper pour (for testing 100pF in paralel with 10nF capacitor to emulate HBM-Human Body Model) => To be tested
      Supercapacitor can be charged under 2.2V but it will be slower charging
      Reg_Out will give 3V only in LDO mode (buck and LDO work only for Supercap. charging)
      Reg_Out voltge is controlled only by VID resistor (should give 2.5V when it is not populated) -Reg_out is not working
      Solutions> working with the sys voltage (2.2 to 3.3V range instead of 3.8V max). It should work pretty well (there will be ~5 days lost for a 10F capacitor-it should be 14 days capable) -Aborted(~20% capacity loss)
      Solved=> REG_OUT FB not soldered properly, after conection REG_OUT supplies 3V at V_SUPERCAP> 3V
      REG_D1 and REG_D2 controls mode of operation (now is connected with either VSYS or GND -for LDO or VIN Hybrid Mode, JUMPER for VDD should be connected)
      VDD can be connected to VSYS with VDD jumper(REG_OUT should be connected instead from capacitor to maintain max 3V at VDD)
      WORKING!!!! MINOP pin was not soldered properly (BOOST converter wasn't switching because the threshold was higher than input - that's why it worked at 3V not at 0.5V)
      
      IMPROVEMENTS> VDD=REG_OUT (3V) not VSYS(2.2 to 3.8V), TEST point for SUPERCAPCAP voltage measurement and VSYS(can be used for safe discharge of the supercapacitor)
      PGOOD and LLD are not very usefull, more usefull will be the measurement o SCAP voltage (simple N+P channel MOS with 1M resistance at gate +1/2 divider (two 1M resistors)=>4 resistors of 1M (good tolerance will be beneficial), and             DMC2400UV as used in Nordic Thingy:52-command from microcontroller to open
PICT0009
- [x] STM32L431(working, Reset pin would be usefull for programming using st-link)
- [ ] Lora (SX1280)(reset and DIO1 are not connected => slow speed of the transceiver

>Sensors
- [x] ENS210 (Temp+Humidity)(both working, tested in ArduinoIDE using STM32Duino and Wire, SoftwareSerial for UART2 transmission)
- [x] LTR-390-UV (Light intensity & UV)(tested in both UVS and ALS, precise, fast-up to 20bits of resolution -could be used to determine weather or not energi is produced from solar)
- [x] DS18-B20 (Surface temperature)(working, not very precise at 2.9V but variation of temperature is working)
- [ ] Analog PH (PH of water)(to be tested-no ph probe available)

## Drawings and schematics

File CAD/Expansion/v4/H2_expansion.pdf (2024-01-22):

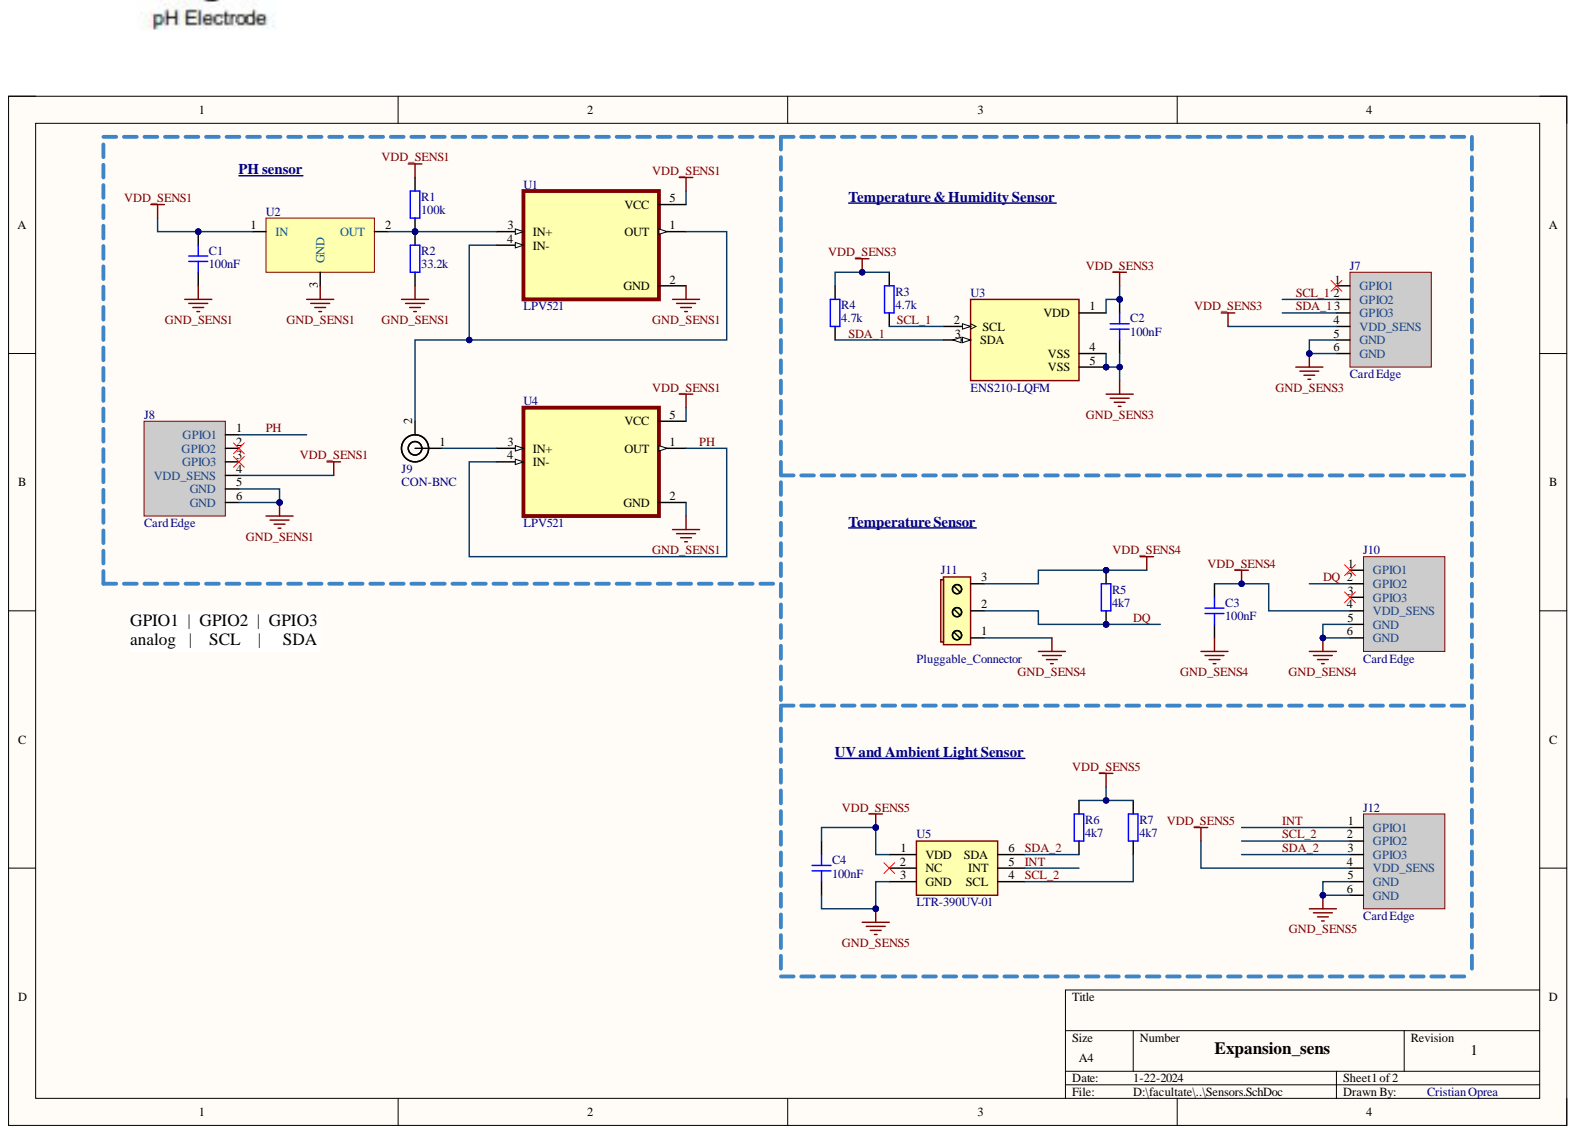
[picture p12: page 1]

Siz e A4 | Numb e r Expansion_se n s | R evisio n 1

Da te : 1-22-2 0 24 | She et of 1 2
File : D:\fa cultate\. .\S enso r s . S c hD o c | Dr awn B y : C ristian Opr e a

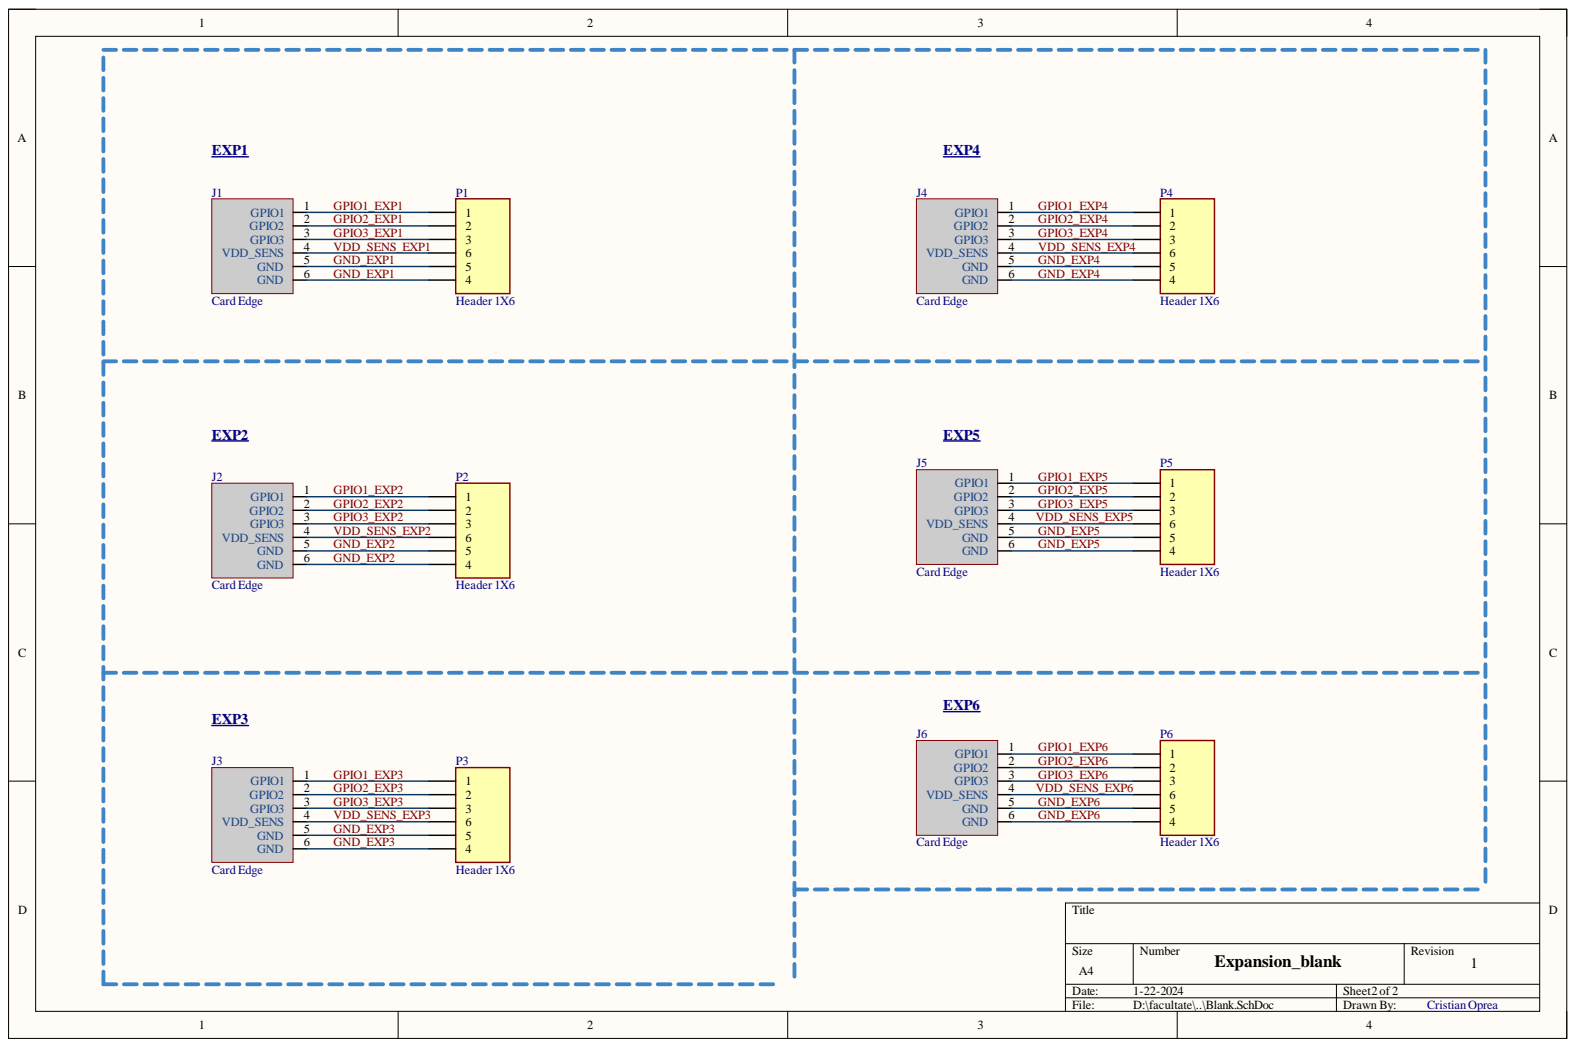
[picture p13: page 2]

Siz e A4 | Numb e r Expansion_bla n k | R evisio n 1

Da te : 1-22-2 0 24 | She et of 2 2
File : D:\fa cultate\. .\Bla nk . S c hD o c | Dr awn B y : C ristian Opr e a

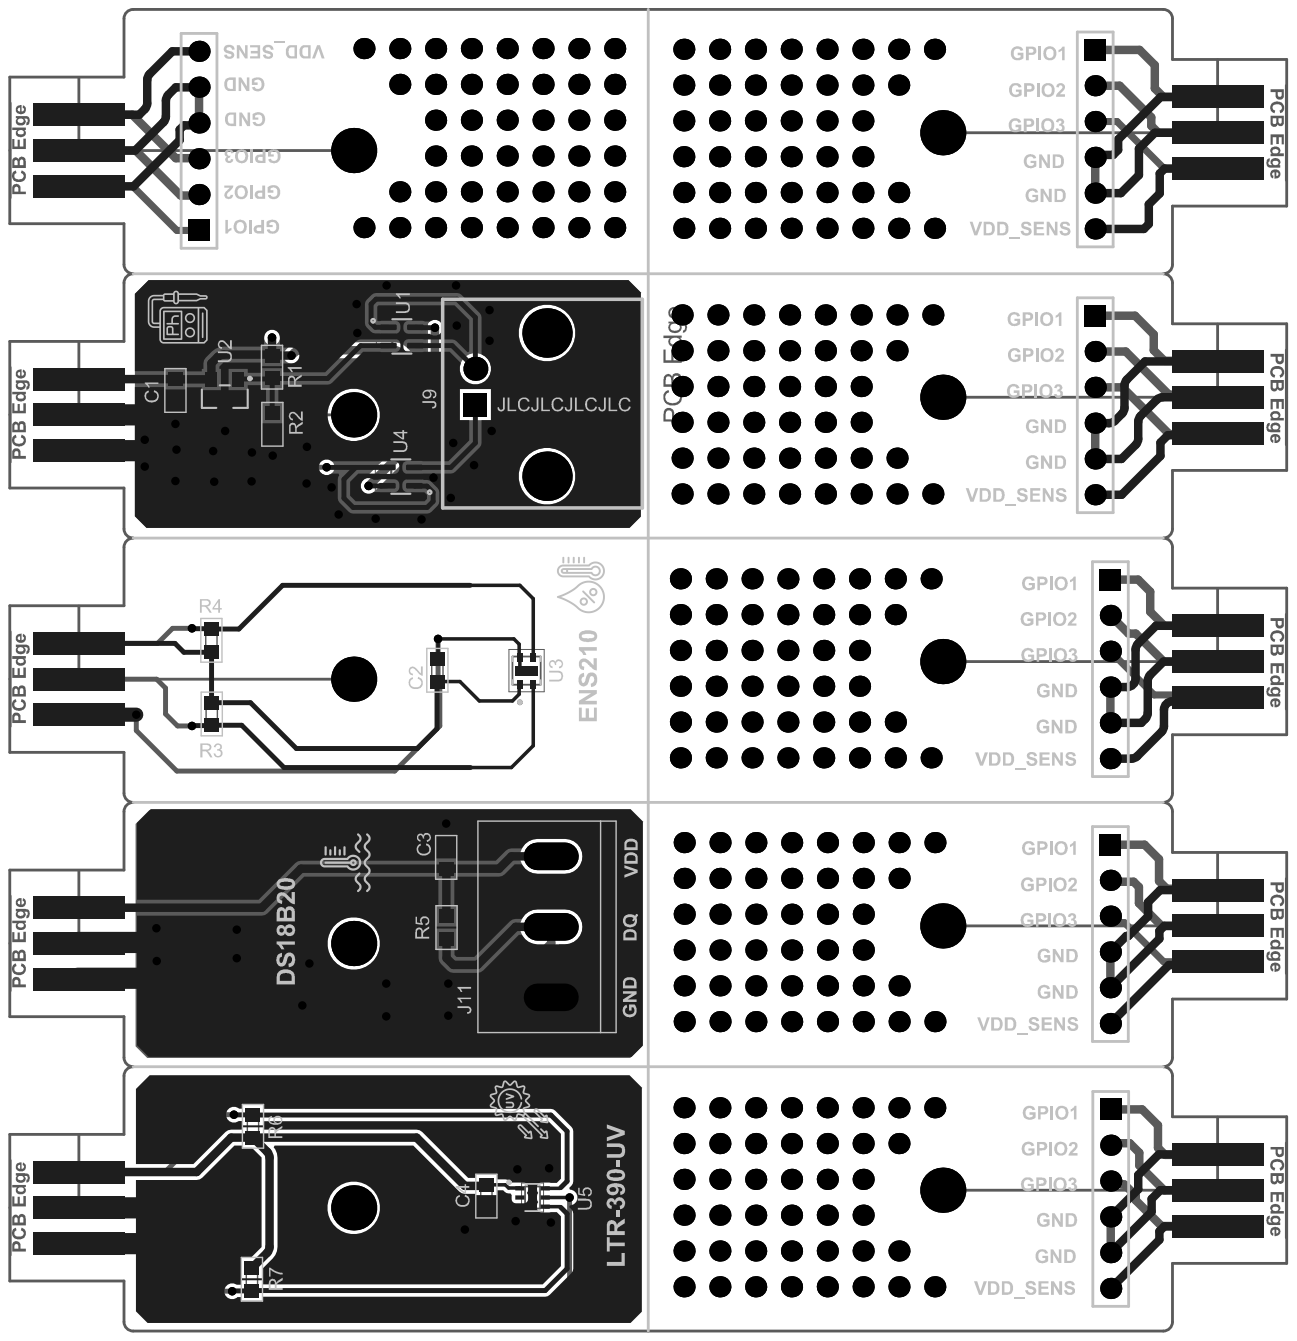
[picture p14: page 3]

Comment | Description | Designator | Footprint | LibRef | Quantity
100nF | Capacitor SMD 0603 | C1, C2, C3, C4 | C0603 | CAP_0603 | 4
Card Edge | Card Edge pads for 2.54 mm pitch edge connector | J1, J2, J3, J4, J5, J6, J7, J8, J10, J12 | Card Edge | Card Edge | 10
CON-BNC | RF Connector BNC Female 50 Ohms PCB TH Mount | J9 | CON_BNC_MOLEX_07 31375003 | CON-BNC | 1
Pluggable_Connector | Screw terminal or plug terminal | J11 | 5mm_screw_terminal_ 3_pos | Pluggable_Connector | 1
Header 1X6 | Header,6-Pin, Single row | P1, P2, P3, P4, P5, P6 | HDR2X32 | Header 1X6 | 6
100k | Resistor SMD 0603 | R1 | R0603 | RES_0603 | 1
33.2k | Resistor SMD 0603 | R2 | R0603 | RES_0603 | 1
4.7k | Resistor SMD 0603 | R3, R4 | R0603 | RES_0603 | 2
4k7 | Resistor SMD 0805 | R5, R6, R7 | R0603 | RES_0805 | 3
LPV521 | | U1, U4 | SOT65P210X110-5N | LPV521 | 2
ADR5040BKSZ-REEL7 | Voltage References 2.048 Low-Cost, Micropower, Low-Dropout, High-Output-Current, SOT23 | U2 | SOT23-3 | VREF | 1
ENS210-LQFM | Humidity/Temperature Sensor Digital Serial (2-Wire, I2C) 4-Pin QFN EP T/R | U3 | XDCR_ENS210-LQFM | ENS210-LQFM | 1
LTR-390UV-01 | SENSOR OPT ULTRAVIOLET 6PINS | U5 | LTR390-UV | LTR-390UV-01 | 1

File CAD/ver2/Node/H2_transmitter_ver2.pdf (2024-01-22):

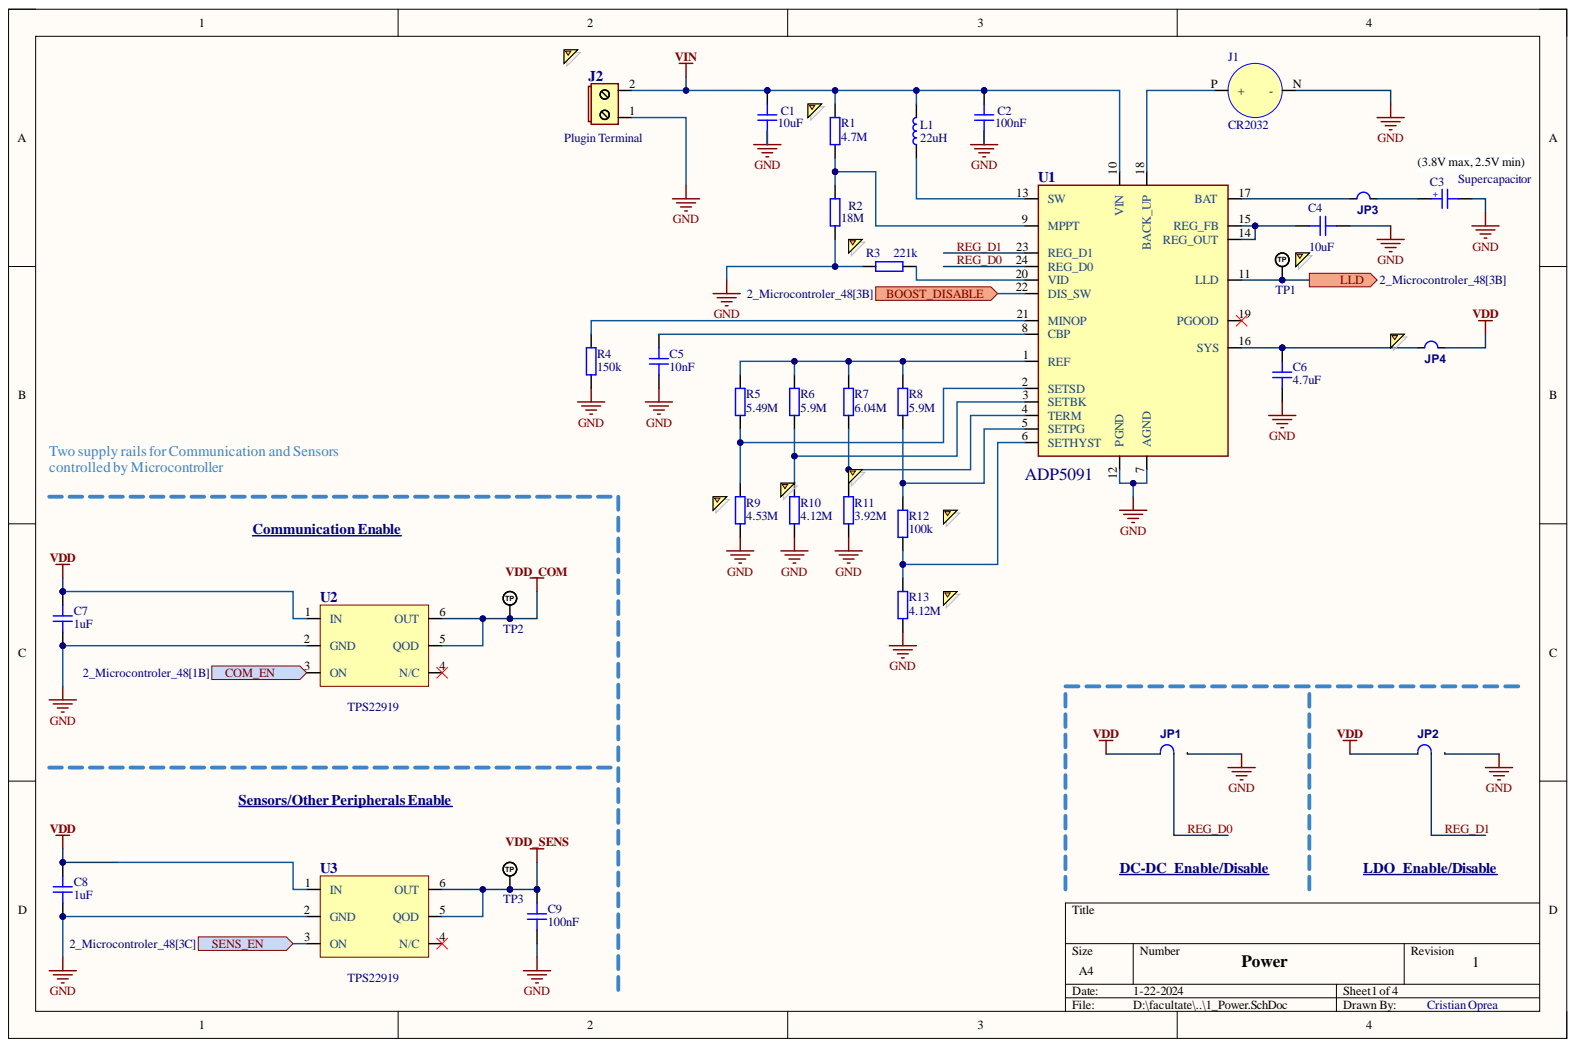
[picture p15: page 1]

Siz e A4 | Numb e r Powe r | R evisio n 1

Da te : 1-22-2 0 24 | She et of 1 4
File : D:\fa cultate\. .\1_P o w e r . S c hD o c | Dr awn B y : C ristian Opr e a

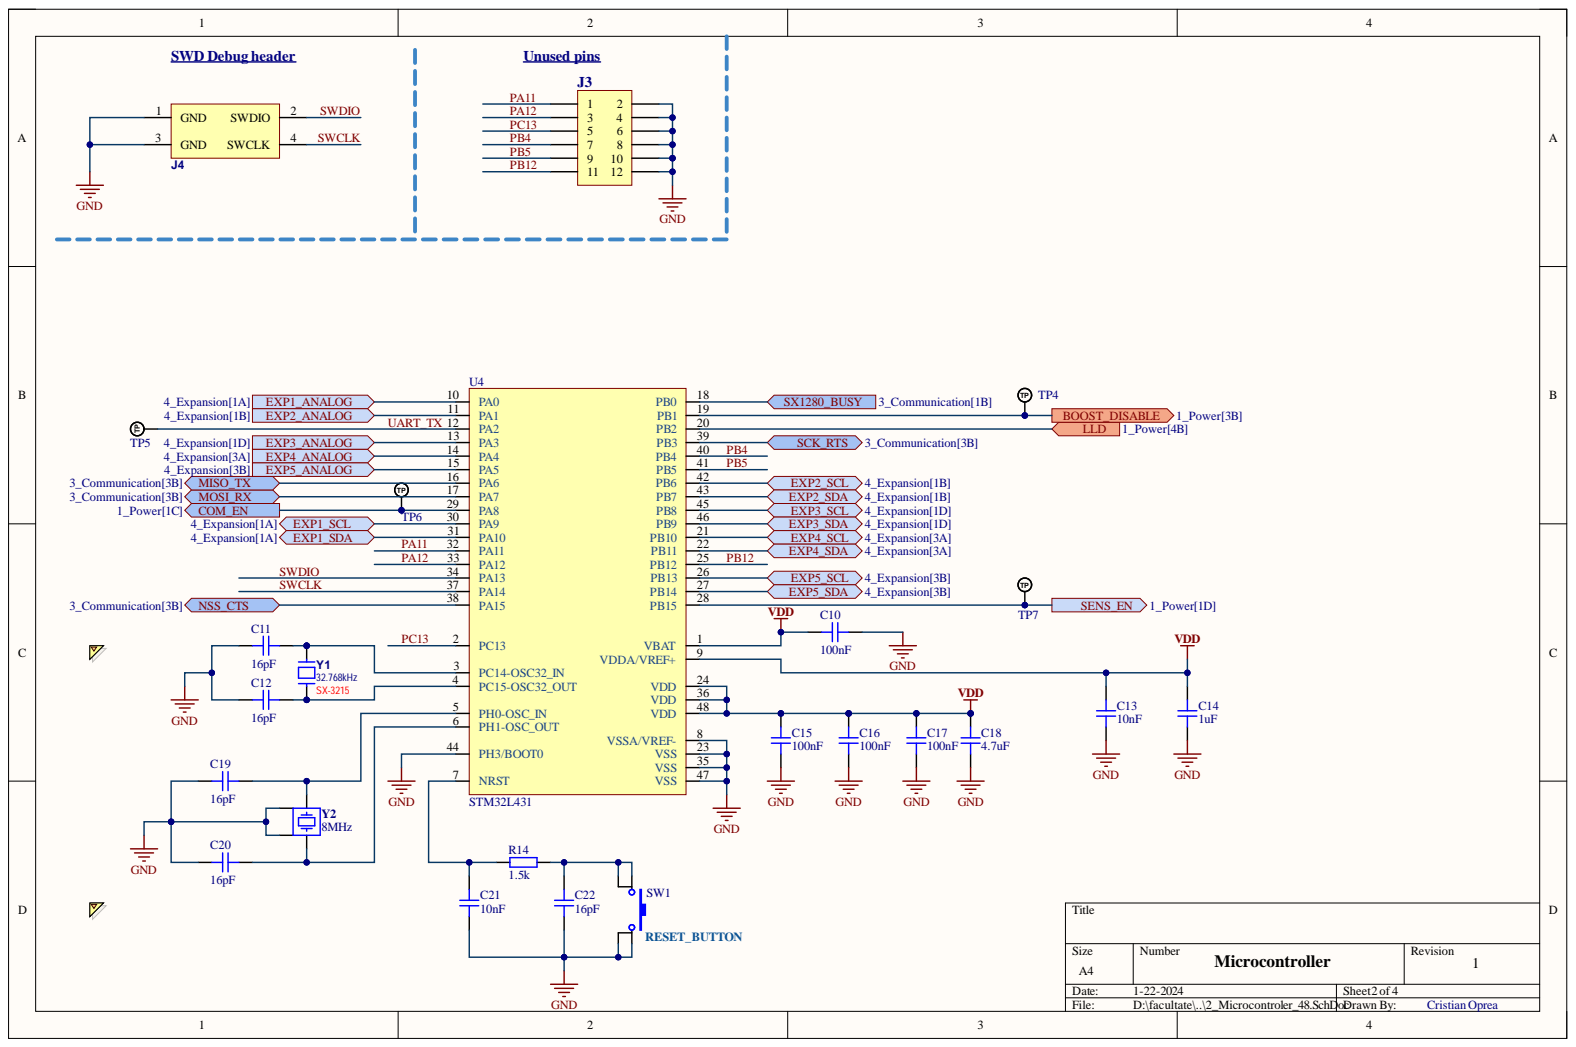
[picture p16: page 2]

C12 | | PC14-OSC32_IN 3

GND

SX-3215 | PH0-OSC_IN 5

PC15-OSC32_OUT 4

PH3/BOOT0 44

NRST 7

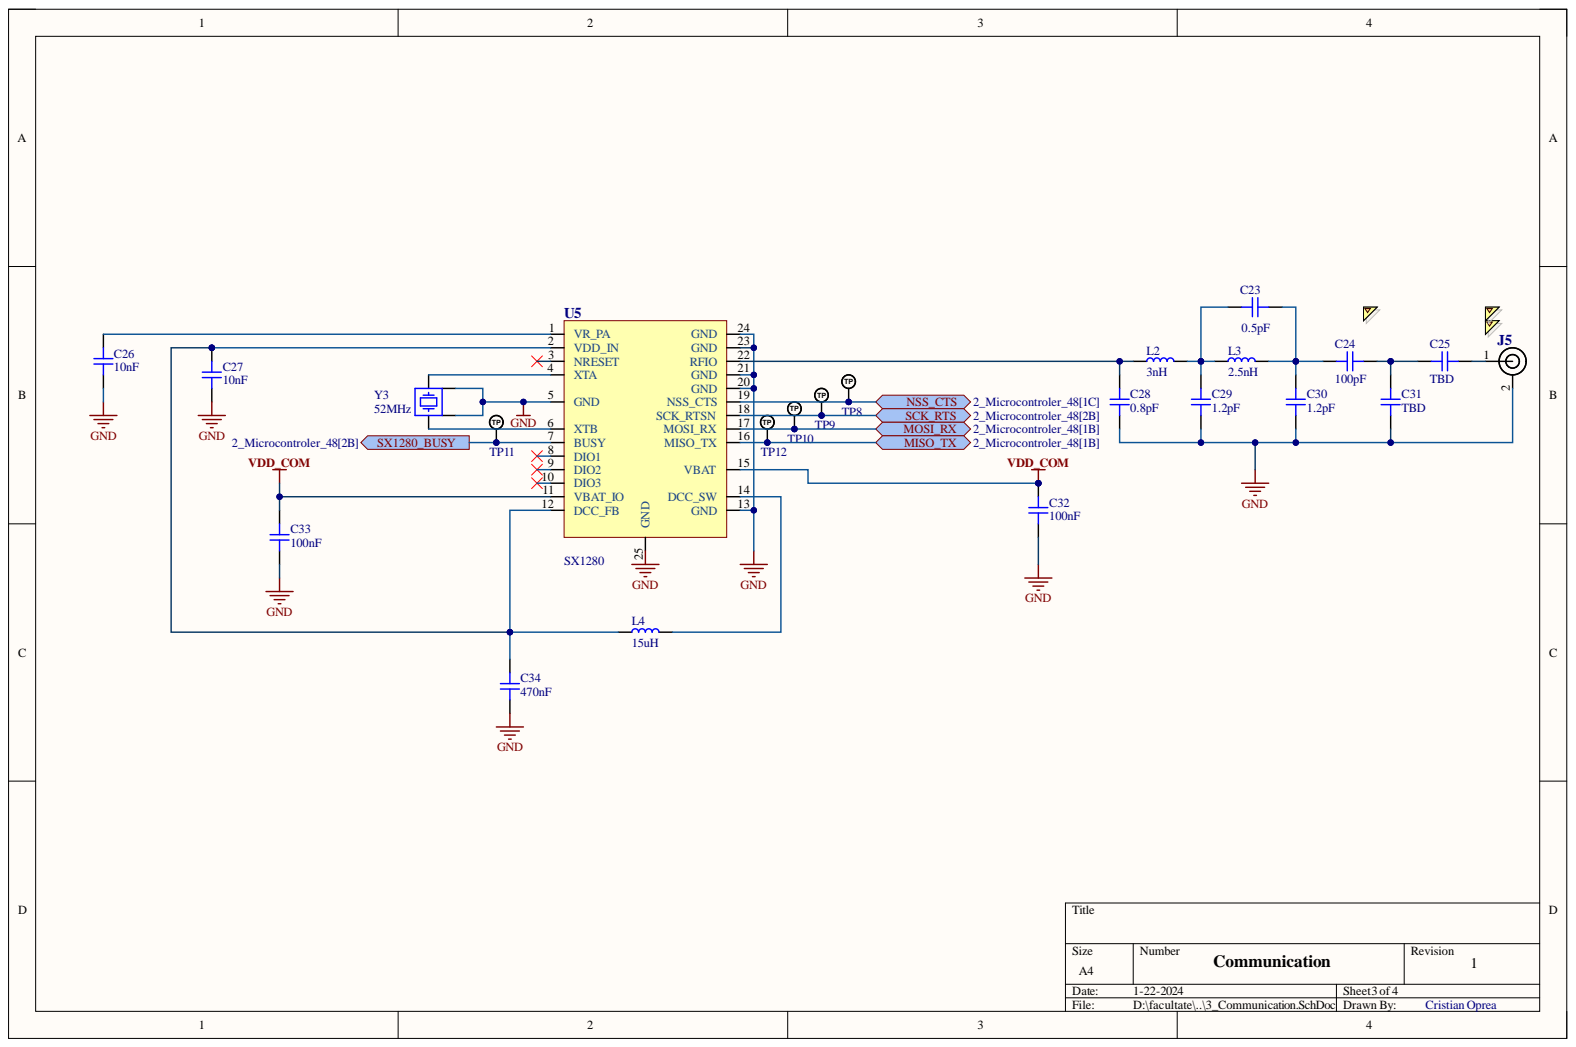
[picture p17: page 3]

Siz e A4 | Numb e r Communicati o n | R evisio n 1

Da te : 1-22-2 0 24 | She et of 3 4
File : D:\fa cultate\. .\3_Communic ati o n . S c hD o c | Dr awn B y : C ristian Opr e a

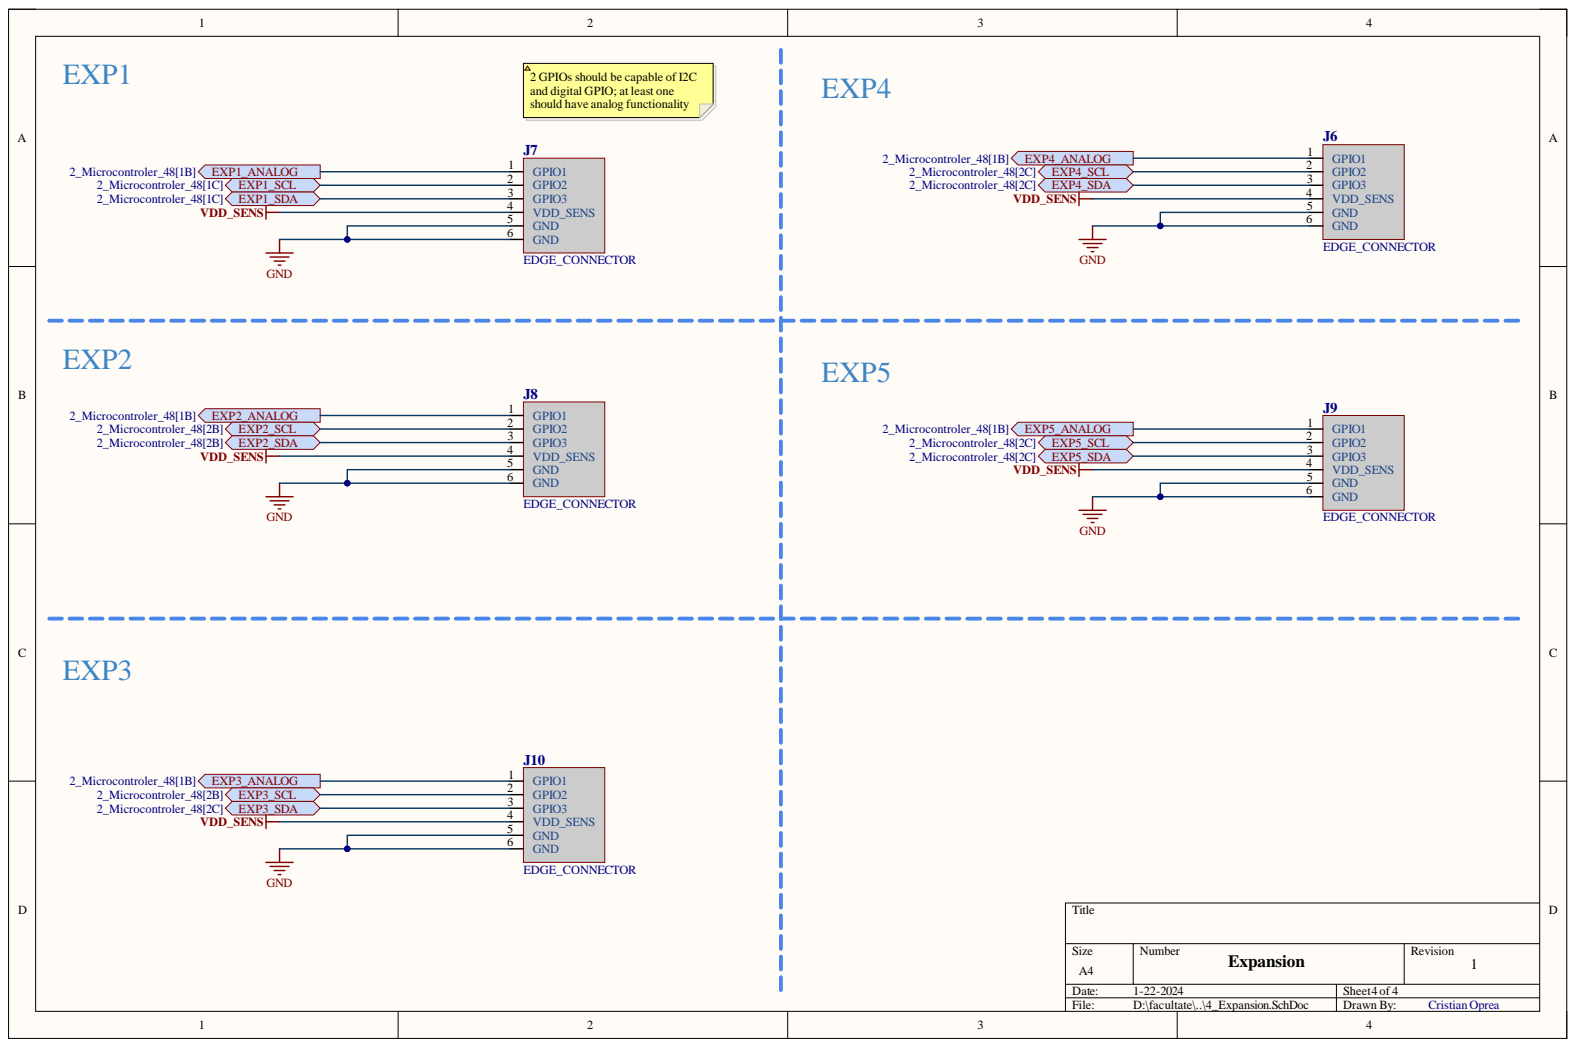
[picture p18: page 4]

2 GPIOs should be capable of I2C
and digital GPIO; at least one
should have analog functionality

Size A4 | Number Expansion | Revision 1

Date: 1-22-2024 | Sheet of 4 4
File: D:\facultate\..\4_Expansion.SchDoc | Drawn By: Cristian Oprea

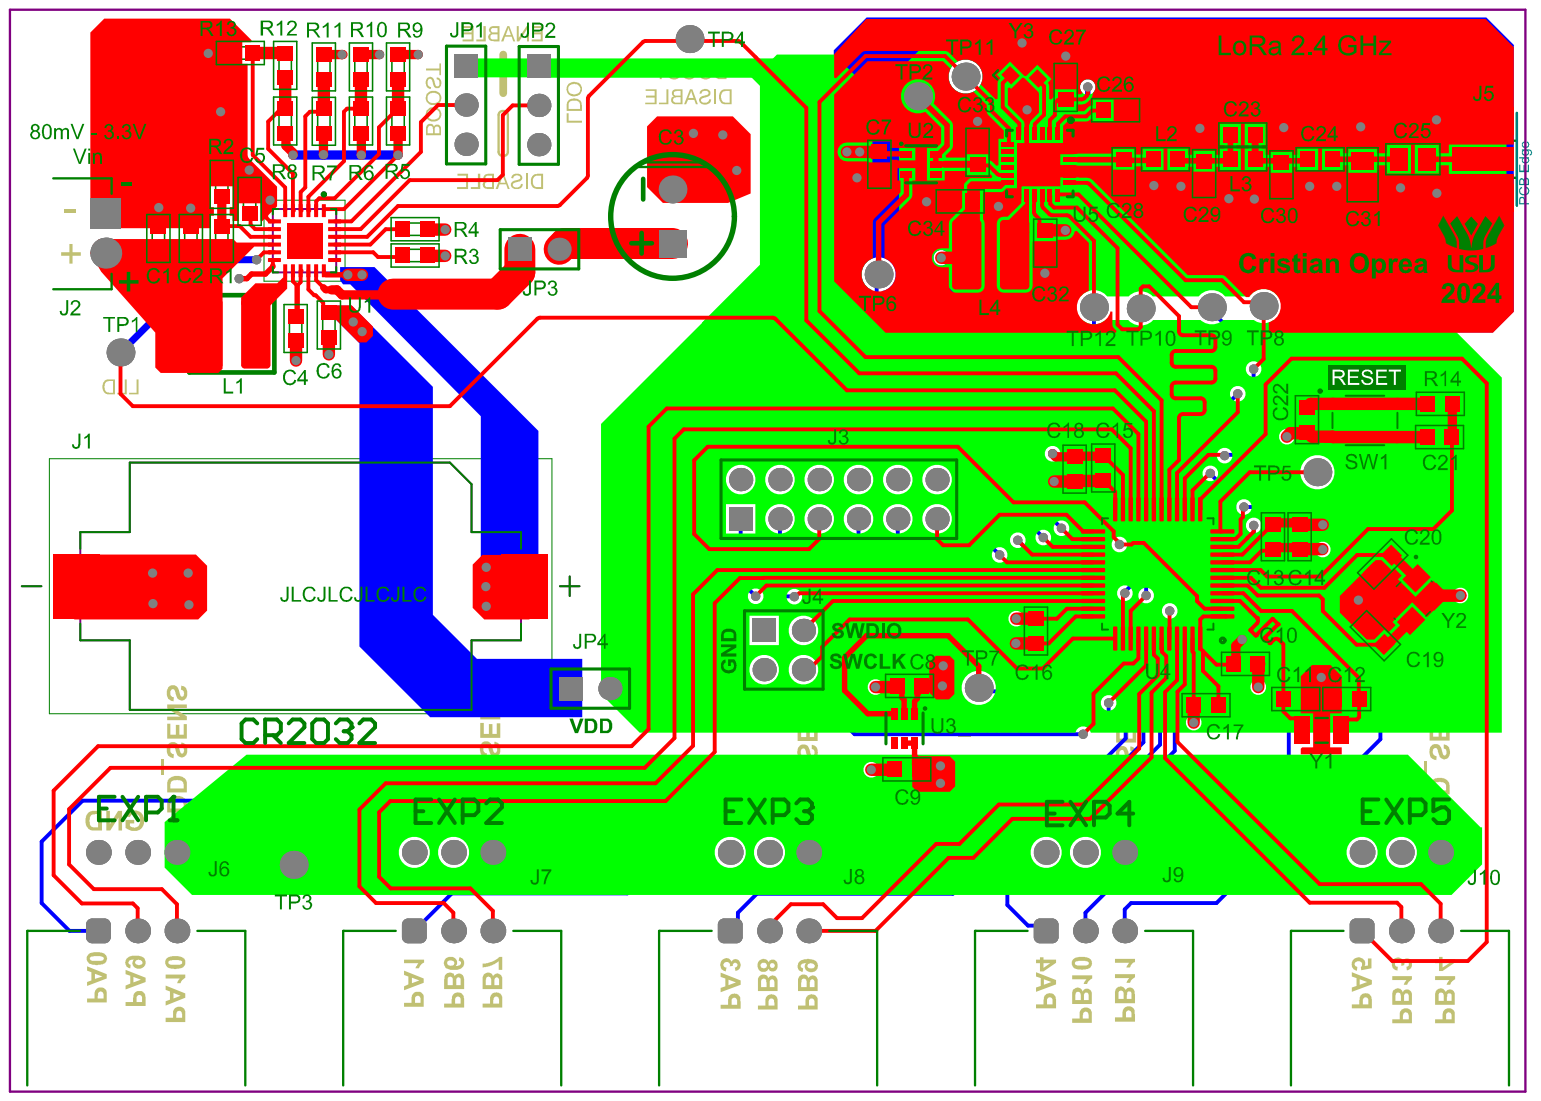
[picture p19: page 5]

Comment | Description | Designator | Footprint | LibRef | Quantity
10uF | Capacitor SMD 0603 | C1, C4 | C0603 | CAP_0603 | 2
100nF | Capacitor SMD 0603 | C2, C9, C10, C15, C16, C17, C32, C33 | C0603 | CAP_0603 | 8
Supercapacitor | Supercapacitor | C3 | CAP_POL_8x16x3.5 | Supercapacitor | 1
10nF | Capacitor SMD 0603 | C5, C13, C21, C26, C27 | C0603 | CAP_0603 | 5
4.7uF | Capacitor SMD 0603 | C6, C18 | C0603 | CAP_0603 | 2
1uF | Capacitor SMD 0603 | C7, C8, C14 | C0603 | CAP_0603 | 3
16pF | Capacitor SMD 0603 | C11, C12, C19, C20, C22 | C0603 | CAP_0603 | 5
0.5pF | Capacitor SMD 0603 | C23 | C0603 | CAP_0603 | 1
100pF | Capacitor SMD 0603 | C24 | C0603 | CAP_0603 | 1
TBD | Capacitor SMD 0805 | C25, C31 | C0805 | CAP_0603 | 2
0.8pF | Capacitor SMD 0603 | C28 | C0603 | CAP_0603 | 1
1.2pF | Capacitor SMD 0603 | C29, C30 | C0603 | CAP_0603 | 2
470nF | Capacitor SMD 0603 | C34 | C0603 | CAP_0603 | 1
CR2032 | CR2032 Coin Cell Battery Holder | J1 | BAT_CR2032-BS-6-1 | CR2032-BS-6-1 | 1
Plugin Terminal | Screw terminal or plug terminal for power | J2 | 2.54_pluggable_termi nal | Power_Connector | 1
Header 6X2 | Header, 12-Pin, Dual row | J3 | HEADER_6x2_2.54 | Header 6x2 | 1
SWD connector | Single Wire Debug connector with UART _TX pin | J4 | HEADER_2x2_2.54 | SWD connector | 1
SMA_EDGE_CONN | RF Connector SMA Female 50 Ohms 18 GHz PCB Edge Mount | J5 | CON_SMA-EDGE-S | CON-SMA-EDGE-S | 1
EDGE_CONNECTOR | Connector for sensor modules | J6, J7, J8, J9, J10 | 2.54mm_edge_connec tor | edge_connector | 5
JUMPER_3PIN | | JP1, JP2 | HEADER_1x3_2.54 | JUMPER_3PIN | 2
JUMPER | | JP3, JP4 | HEADER_1x2_2.54 | JUMPER | 2
22uH | Inductor SMD 1008 | L1 | IND_3.2_4 | IND_1008 | 1
3nH | Inductor SMD 0603 | L2 | R0603 | IND_0603 | 1
2.5nH | Inductor SMD 0603 | L3 | R0603 | IND_0603 | 1
15uH | Inductor SMD 0603 | L4 | IND_3.2_4 | IND_0603 | 1
4.7M | Resistor SMD 0603 | R1 | R0603 | RES_0603 | 1
18M | Resistor SMD 0603 | R2 | R0603 | RES_0603 | 1
221k | Resistor SMD 0603 | R3 | R0603 | RES_0603 | 1
150k | Resistor SMD 0603 | R4 | R0603 | RES_0603 | 1
5.49M | Resistor SMD 0603 | R5 | R0603 | RES_0603 | 1
5.9M | Resistor SMD 0603 | R6, R8 | R0603 | RES_0603 | 2
6.04M | Resistor SMD 0603 | R7 | R0603 | RES_0603 | 1
4.53M | Resistor SMD 0603 | R9 | R0603 | RES_0603 | 1
4.12M | Resistor SMD 0603 | R10, R13 | R0603 | RES_0603 | 2
3.92M | Resistor SMD 0603 | R11 | R0603 | RES_0603 | 1
100k | Resistor SMD 0603 | R12 | R0603 | RES_0603 | 1
1.5k | Resistor SMD 0603 | R14 | R0603 | RES_0603 | 1
PTS645SM43SMTR92 LFS | Switch | SW1 | SW_SKRPACE010 | SW-PB | 1
ADP5091 | Ultralow Power Energy Harvester PMUs with MPPT and Charge Management and BAckup Supply | U1 | LFCSP-24 | ADP5091 | 1
TPS22919 | 5.5-V, 1.5-A, 90-mΩ load switch with adjustable output discharge | U2, U3 | SC70-6 | TPS22919 | 2
STM32L431 | Ultra-low-power Arm® Cortex®-M4 32-bit MCU+FPU, 100DMIPS, up to 128KB flash, 40KB SRAM(LQFP48) | U4 | QFPN-48 | STM32L431 | 1
SX1280 | Low power LoRa transceiver operating at 2.4GHz with ranging capability | U5 | QFN-24_4x4_0.5 | SX1280 | 1
32.768kHz | Crystal | Y1 | CRYSTAL_SX-3215 | CRYSTAL_1 | 1
8MHz | Crystal | Y2 | CRYSTAL_ECX-32_3.2x2.5x0.8 -duplicate | Crystal | 1
52MHz | Crystal | Y3 | CRYSTAL_2016_4P | Crystal | 1

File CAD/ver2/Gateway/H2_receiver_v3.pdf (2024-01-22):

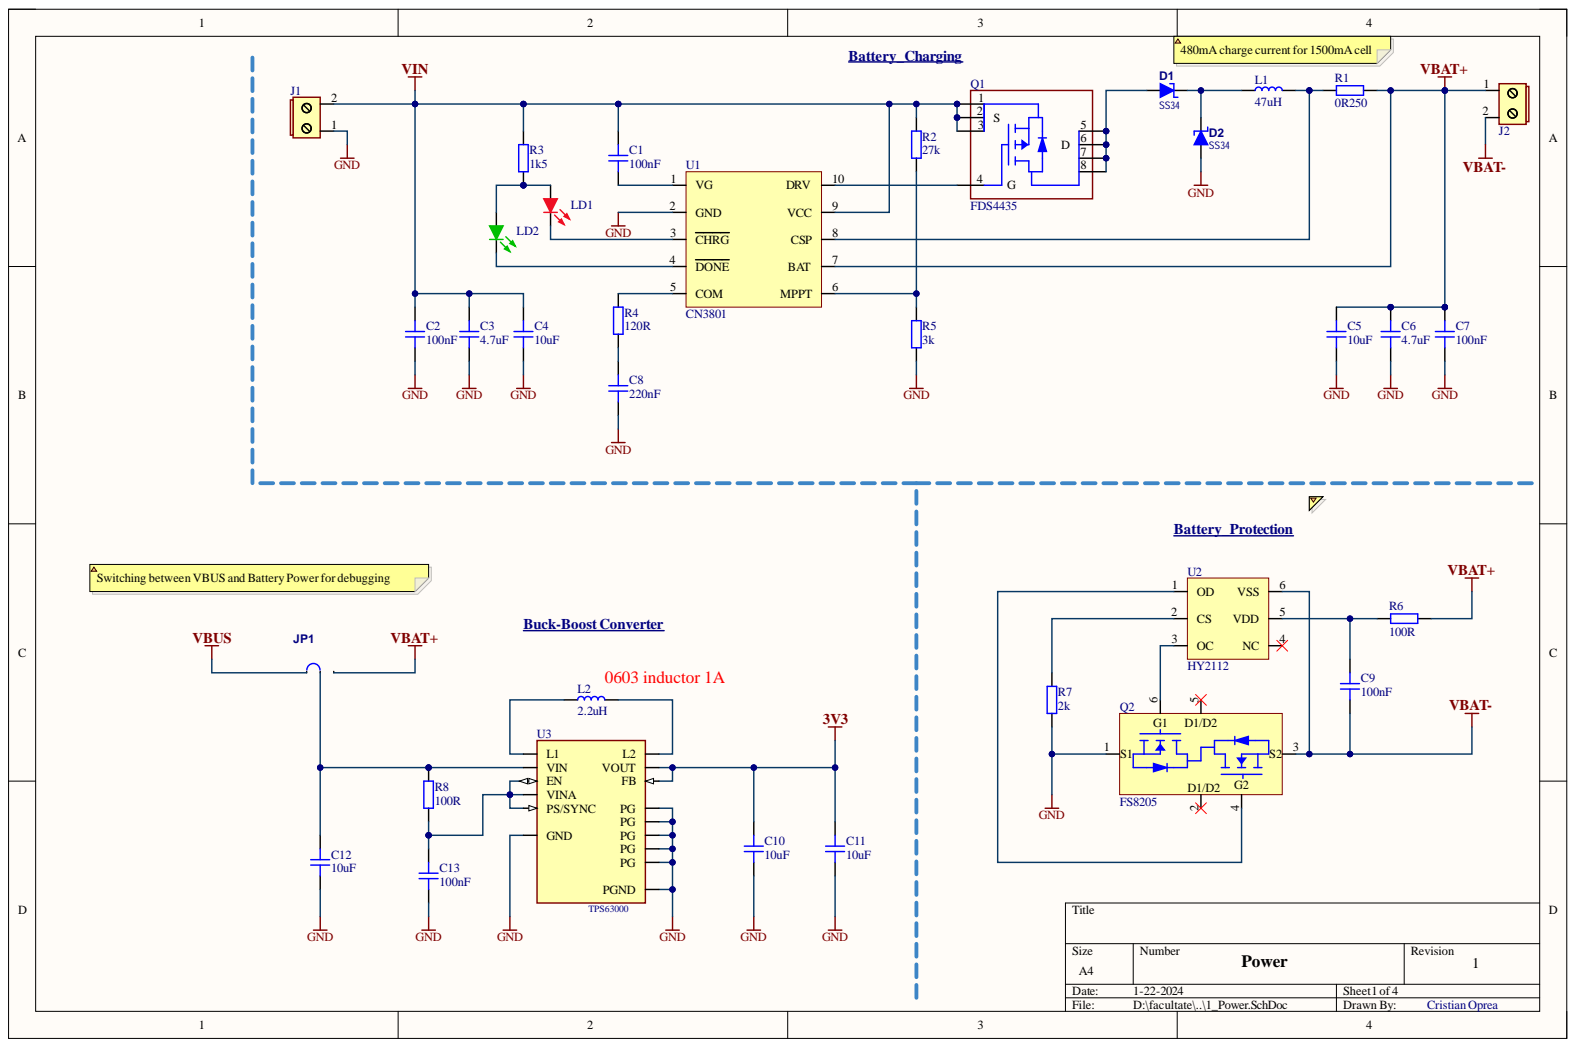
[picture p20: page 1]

480mA charge current for 1500mA cell

Switching between VBUS and Battery Power for debugging

Size A4 | Number Power | Revision 1

Date: 1-22-2024 | Sheet of 1 4
File: D:\facultate\..\1_Power.SchDoc | Drawn By: Cristian Oprea

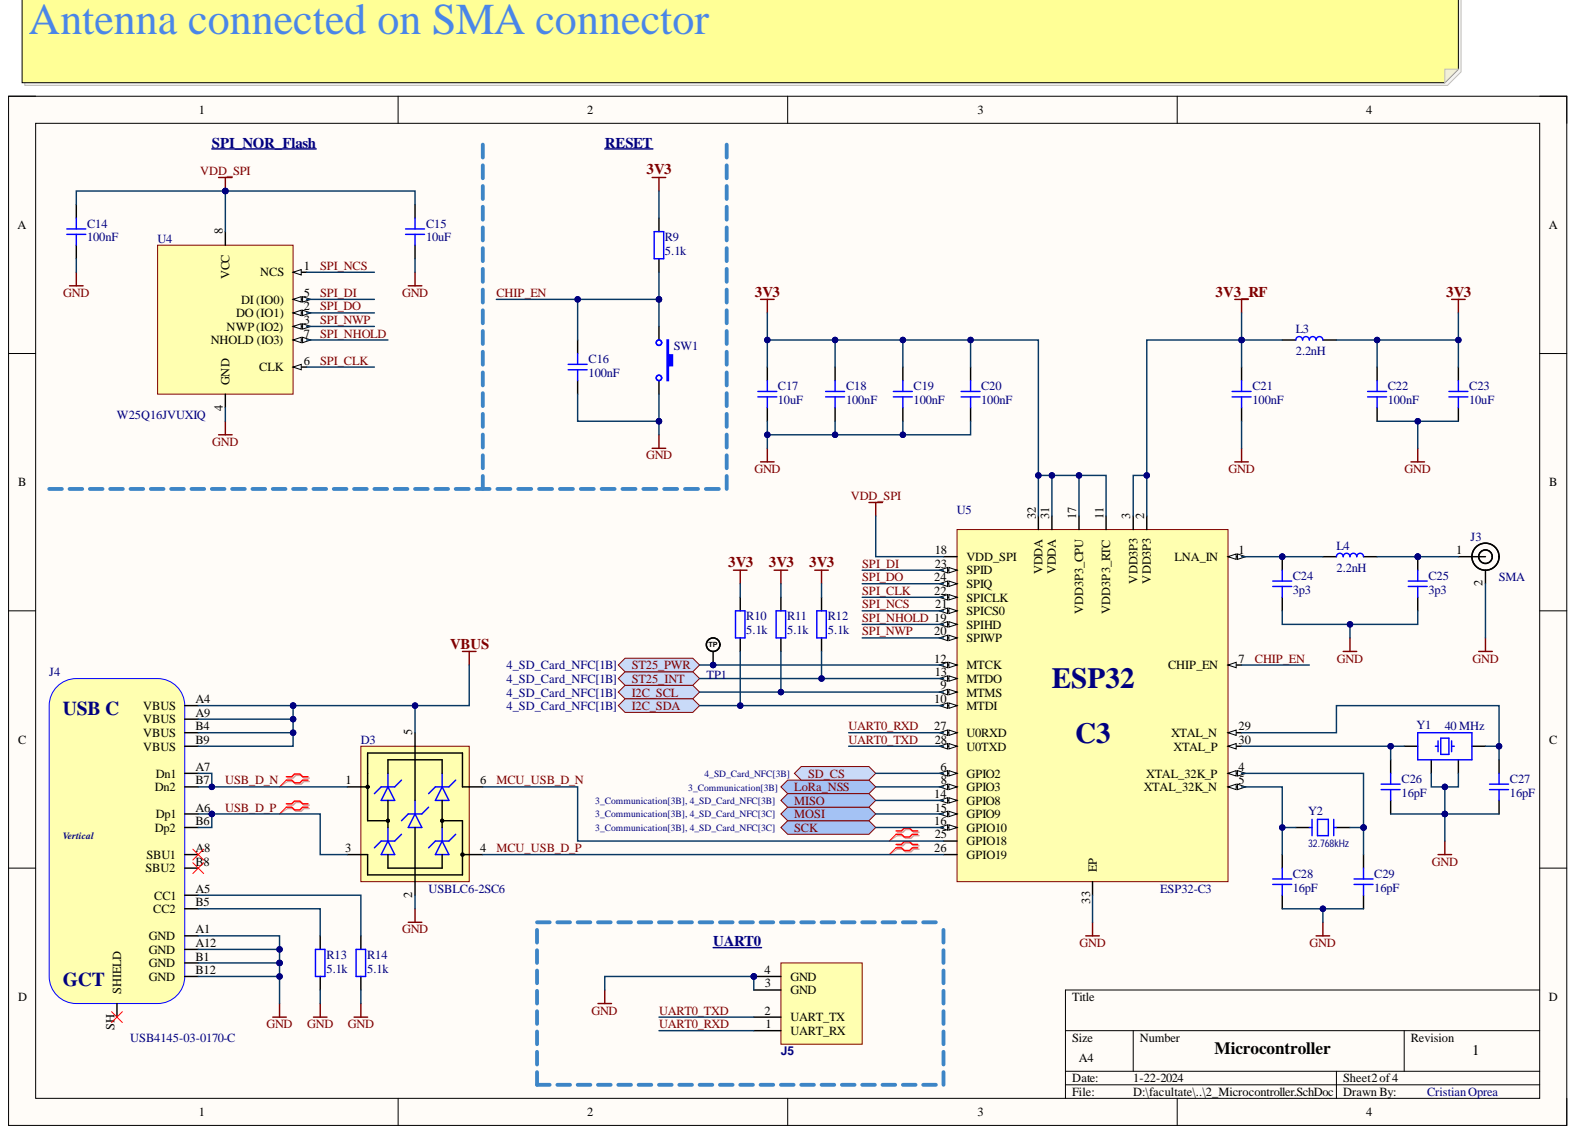
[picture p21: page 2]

Antenna connected on SMA connector

Siz e A4 | Numb e r Microcontrolle r | R evisio n 1

Da te : 1-22-2 0 24 | She et of 2 4
File : D:\fa cultate\. .\2_Mic rocontr o lle r . S c hD o c | Dr awn B y : C ristian Opr e a

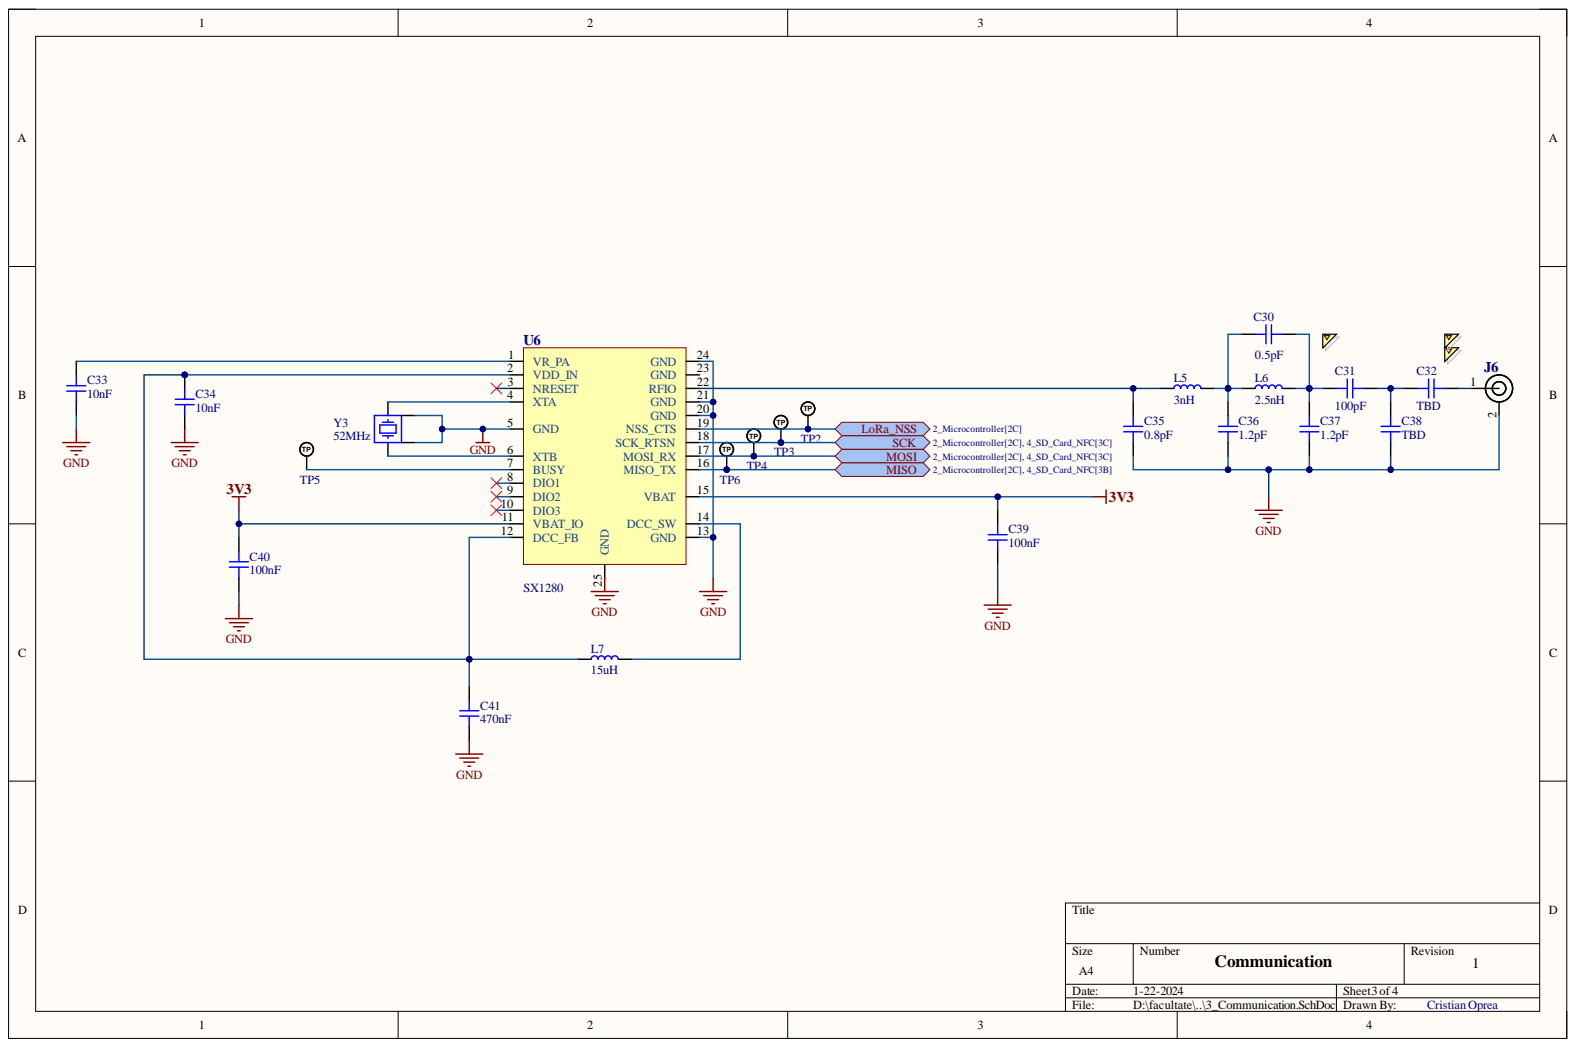
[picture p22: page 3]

Siz e A4 | Numb e r Communicati o n | R evisio n 1

Da te : 1-22-2 0 24 | She et of 3 4
File : D:\fa cultate\. .\3_Communic ati o n . S c hD o c | Dr awn B y : C ristian Opr e a

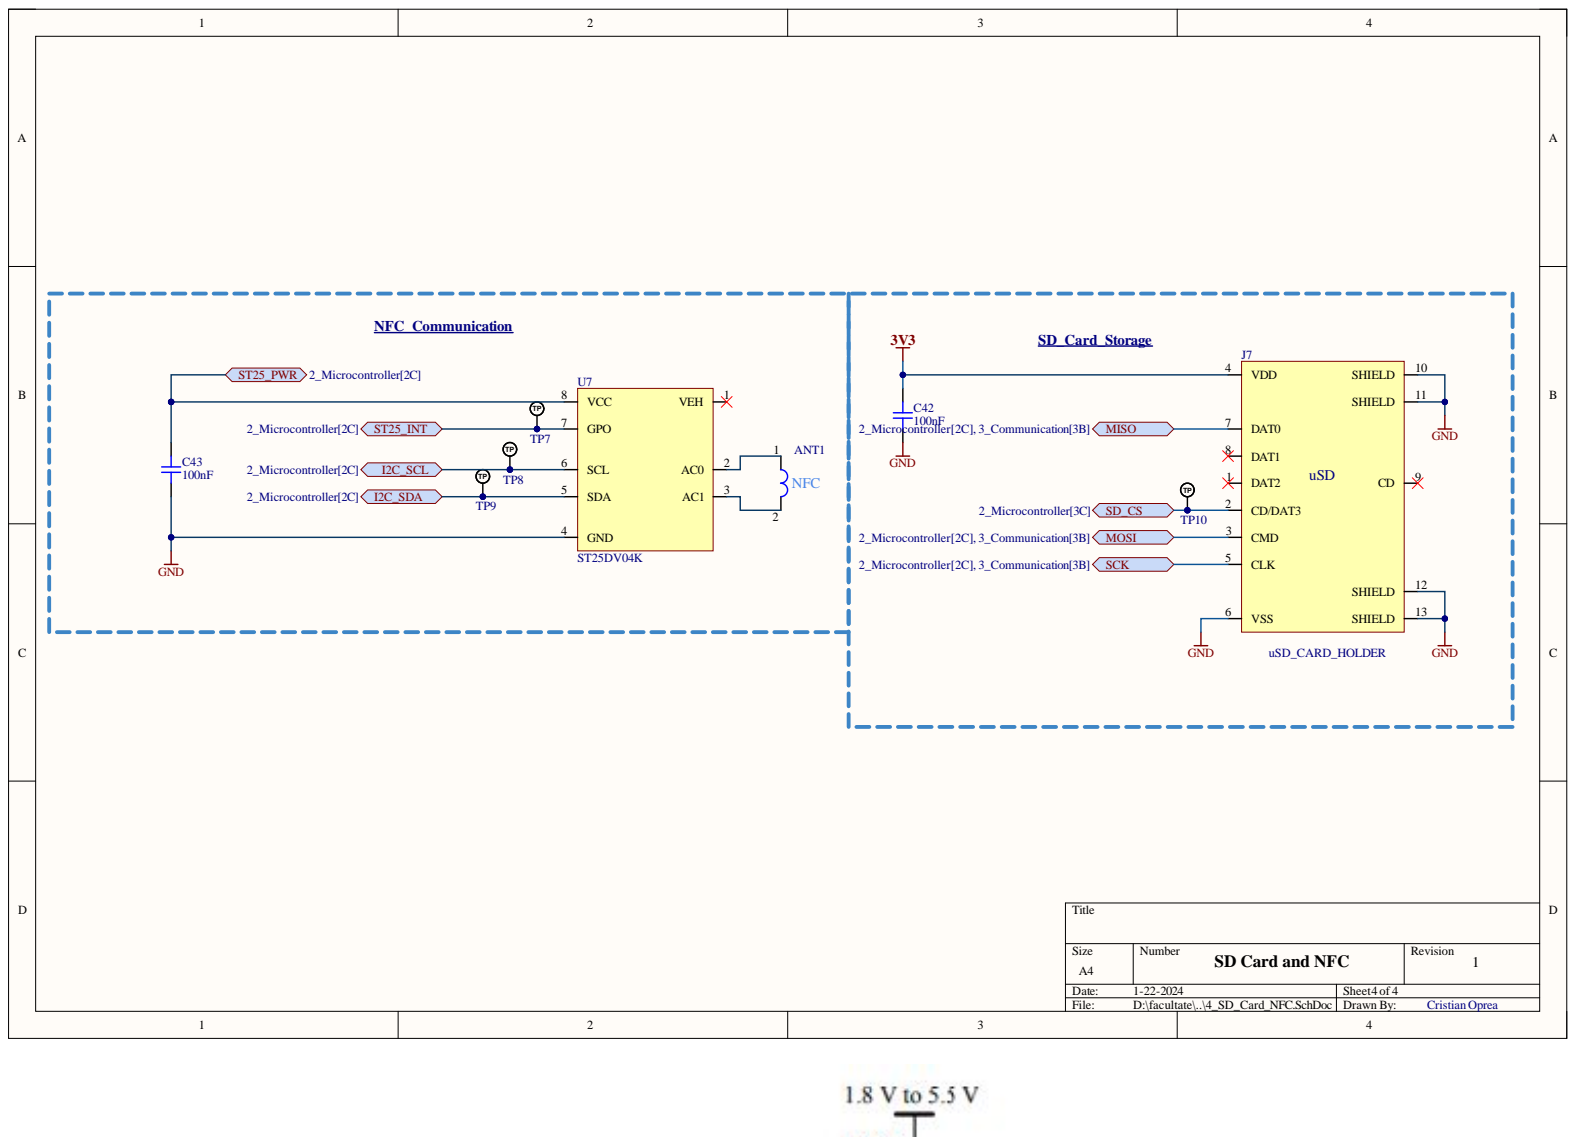
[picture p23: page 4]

Siz e A4 | Numb e r SD Card and NFC | R evisio n 1

Da te : 1-22-2 0 24 | She et of 4 4
File : D:\fa cultate\. .\4_SD_C a r d_NFC . S c hD o c | Dr awn B y : C ristian Opr e a


Comment | Description | Designator | Footprint | LibRef | Quantity
NFC_ANTENNA | | ANT1 | ANT16 | NFC_ANTENNA | 1
100nF | Capacitor SMD 0603 | C1, C2, C7, C9, C13, C14, C16, C18, C19, C20, C21, C22, C39, C40, C42, C43 | C0603 | CAP_0603 | 16
4.7uF | Capacitor SMD 0603 | C3, C6 | C0603 | CAP_0603 | 2
10uF | Capacitor SMD 0805 | C4, C5, C10, C11, C12, C15, C17, C23 | C0805 | CAP_0805 | 8
220nF | Capacitor SMD 0603 | C8 | C0603 | CAP_0603 | 1
3p3 | Capacitor SMD 0603 | C24, C25 | C0603 | CAP_0603 | 2
16pF | Capacitor SMD 0603 | C26, C27, C28, C29 | C0603 | CAP_0603 | 4
0.5pF | Capacitor SMD 0603 | C30 | C0603 | CAP_0603 | 1
100pF | Capacitor SMD 0603 | C31 | C0603 | CAP_0603 | 1
TBD | Capacitor SMD 0805 | C32, C38 | C0805 | CAP_0603 | 2
10nF | Capacitor SMD 0603 | C33, C34 | C0603 | CAP_0603 | 2
0.8pF | Capacitor SMD 0805 | C35 | C0603 | CAP_0805 | 1
1.2pF | Capacitor SMD 0603 | C36, C37 | C0603 | CAP_0603 | 2
470nF | Capacitor SMD 0603 | C41 | C0603 | CAP_0603 | 1
SS34 | Diode | D1, D2 | DO-214AC | DIODE_SCHOTTKY | 2
USBLC6-2SC6 | Low-Capacitance ESD Protection USB | D3 | SOT23-6 | USBLC6-2SC6 | 1
PLUGIN_TERMINAL | Screw terminal or plug terminal for power | J1 | 2.54_pluggable_termi nal | Power_Connector | 1
PLUGIN_TERMINAL | Screw terminal or plug terminal for power | J2 | HEADER_1x2_2.54 | Power_Connector | 1
SMA | RF Connector SMA Female 50 Ohms 18 GHz PCB Edge Mount | J3 | CON_SMA-EDGE-S | CON-SMA-EDGE-S | 1
USB4145-03-0170-C | USB Connector Type C SMT 16 Pin Vertical | J4 | VALCON_CSP-USC16-TR | USB4145-03-0170-C | 1
Header1x4 | | J5 | HEADER_2x2_2.54 | Header1x4 | 1
SMA_EDGE_CONN | RF Connector SMA Female 50 Ohms 18 GHz PCB Edge Mount | J6 | CON_SMA-EDGE-S | CON-SMA-EDGE-S | 1
uSD_CARD_HOLDER | | J7 | TF115BCP9 | uSD_CARD | 1
JUMPER_3PIN | | JP1 | HEADER_1x3_2.54 | JUMPER_3PIN | 1
47uH | Inductor SMD 0603 | L1 | IND_5_7 | IND_0603 | 1
2.2uH | Inductor SMD 1008 | L2 | L0603 | IND_1008 | 1
2.2nH | Inductor SMD 1008 | L3, L4 | L0603 | IND_1008 | 2
3nH | Inductor SMD 0603 | L5 | L0603 | IND_0603 | 1
2.5nH | Inductor SMD 0603 | L6 | L0603 | IND_0603 | 1
15uH | Inductor SMD 0603 | L7 | IND_3.2_4 | IND_0603 | 1
LED_RED | Typical BLUE SiC LED | LD1 | LED0603RD | LED_RED | 1
LED_GREEN | Typical BLUE SiC LED | LD2 | LED0603GR | LED_GREEN | 1
FDS4435 | | Q1 | SOIC-SN8_N | FDS4435 | 1
FS8205 | | Q2 | SOT23-6 | FS8205 | 1
0R250 | Resistor SMD 0805 | R1 | R2512 | RES_0805 | 1
27k | Resistor SMD 0603 | R2 | R0603 | RES_0603 | 1
1k5 | Resistor SMD 0603 | R3 | R0603 | RES_0603 | 1
120R | Resistor SMD 0603 | R4 | R0603 | RES_0603 | 1
3k | Resistor SMD 0603 | R5 | R0603 | RES_0603 | 1
100R | Resistor SMD 0603 | R6, R8 | R0603 | RES_0603 | 2
2k | Resistor SMD 0603 | R7 | R0603 | RES_0603_1 | 1
5.1k | Resistor SMD 0603 | R9, R10, R11, R12, R13, R14 | R0603 | RES_0603 | 6
PTS645SM43SMTR92 LFS | Switch | SW1 | SW_SKRPACE010 | SW-PB | 1
CN3801 | LiFePO4 charge IC with integrated MPPT and wide input range (4.5 to 28V) with deeply discharged cell revive | U1 | SSOP-10 | CN3801 | 1
HY2112 | LiFePO4 protection IC | U2 | SOT23-6 | HY2112 | 1
TPS63000 | Buck-Boost Switching Regulator IC Positive Adjustable 1.2V 1 Output 1.6A _Switch_ 10-VFDFN Exposed Pad | U3 | VREG_V62/16624-01YE | TPS63000 | 1
W25Q16JVUXIQ | 16M-BIT SERIAL FLASH MEMORY WITH DUAL/QUAD SPI USON-8 | U4 | SOIC-8N_208mil | W25Q16JVUXIQ | 1
ESP32-C3 | Ultra-Low-Power SoC with RISC-V Single-Core CPU Supporting IEEE 802.11b/g/n (2.4 GHz Wi-Fi) and Bluetooth® 5 (LE) | U5 | QFN-32-5x5x0.85mm | ESP32-C3 | 1
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

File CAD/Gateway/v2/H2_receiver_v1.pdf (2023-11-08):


CHR G C S P DO NE B AT C O M MP P T | 8

Siz e A4 | Numb e r | R evisio n

Da te : 11-08-2 0 2 3 | She et of
File : D:\fa cultate\. .\1_P o w e r . S c hD o c | Dr awn B y :


Antenna connected on SMA connector

Siz e A4 | Numb e r | R evisio n

Da te : 11-08-2 0 2 3 | She et of
File : D:\fa cultate\. .\2_Mic rocontr o lle r . S c hD o c | Dr awn B y :


Siz e A4 | Numb e r | R evisio n

Da te : 11-08-2 0 2 3 | She et of
File : D:\fa cultate\. .\3_Communic ati o n . S c hD o c | Dr awn B y :


Siz e A4 | Numb e r | R evisio n

Da te : 11-08-2 0 2 3 | She et of
File : D:\fa cultate\. .\4_SD_C a r d_NFC . S c hD o c | Dr awn B y :

Comment | Description | Designator | Footprint | LibRef | Quantity
NFC_ANTENNA | | ANT1 | | NFC_ANTENNA | 1
100nF | Capacitor SMD 0603 | C1, C2, C5, C9, C10, C11, C16, C18, C20, C21, C22, C23, C24, C42 | CAP_0603 | CAP_0603 | 14
4.7uF | Capacitor SMD 0603 | C3, C6 | CAP_0603 | CAP_0603 | 2
10uF | Capacitor SMD 0805 | C4, C7, C12, C13, C14, C17, C19, C25 | CAP_0805 | CAP_0805 | 8
220nF | Capacitor SMD 0603 | C8 | CAP_0603 | CAP_0603 | 1
0.1uF | Capacitor SMD 0603 | C15 | CAP_0603 | CAP_0603 | 1
3p3 | Capacitor SMD 0603 | C26, C27 | CAP_0603 | CAP_0603 | 2
10pF | Capacitor SMD 0603 | C28, C29, C30, C31 | CAP_0603 | CAP_0603 | 4
C0603 | Capacitor SMD 0603 | C32, C33, C36, C37, C38 | CAP_0603 | CAP_0603 | 5
10n | Capacitor SMD 0603 | C34, C35 | CAP_0603 | CAP_0603 | 2
100n | Capacitor SMD 0603 | C39, C40 | CAP_0603 | CAP_0603 | 2
470n | Capacitor SMD 0603 | C41 | CAP_0603 | CAP_0603 | 1
SS34 | Diode | D1, D2 | DO-213AA | DIODE_SCHOTTKY | 2
USBLC6-2SC6 | Low-Capacitance ESD Protection USB | D3 | SOT-23-6 | USBLC6-2SC6 | 1
PLUGIN_TERMINAL | Screw terminal or plug terminal for power | J1 | | Power_Connector | 1
SMA | RF Connector SMA Female 50 Ohms 18 GHz PCB Edge Mount | J2 | CON-SMA-EDGE-S | CON-SMA-EDGE-S | 1
USB4145-03-0170-C | USB Connector Type C SMT 16 Pin Vertical | J3 | USB4145-03-0170-C | USB4145-03-0170-C | 1
Header1x4 | | J4 | | Header1x4 | 1
SMA_EDGE_CONN | RF Connector SMA Female 50 Ohms 18 GHz PCB Edge Mount | J5 | CON-SMA-EDGE-S | CON-SMA-EDGE-S | 1
uSD_CARD_HOLDER | | J6 | | uSD_CARD | 1
JUMPER_3PIN | | JP1 | JUMPER_SMD_3 | JUMPER_3PIN | 1
47uH | Inductor SMD 0603 | L1 | IND_0603 | IND_0603 | 1
2.2nH | Inductor SMD 1008 | L2, L4, L5 | IND_1008 | IND_1008 | 3
2.2uH | Inductor SMD 1008 | L3 | IND_1008 | IND_1008 | 1
L0603 | Inductor SMD 0603 | L6, L7 | IND_0603 | IND_0603 | 2
15u | Inductor SMD 0603 | L8 | IND_0603 | IND_0603 | 1
LED_RED | Typical BLUE SiC LED | LD1 | 3.5X2.8X1.9 | LED_RED | 1
LED_GREEN | Typical BLUE SiC LED | LD2 | 3.5X2.8X1.9 | LED_GREEN | 1
FDS4435 | | Q1 | | FDS4435 | 1
FS8205 | | Q2 | | FS8205 | 1
0R05 | Resistor SMD 0805 | R1 | RES_0805 | RES_0805 | 1
27k | Resistor SMD 0603 | R2 | RES_0603 | RES_0603 | 1
1k5 | Resistor SMD 0603 | R3 | RES_0603 | RES_0603 | 1
120R | Resistor SMD 0603 | R4 | RES_0603 | RES_0603 | 1
3k | Resistor SMD 0603 | R5 | RES_0603 | RES_0603 | 1
100R | Resistor SMD 0603 | R6, R8 | RES_0603 | RES_0603 | 2
2k | Resistor SMD 0603 | R7 | RES_0603 | RES_0603_1 | 1
5.1k | Resistor SMD 0603 | R9, R13, R14 | RES_0603 | RES_0603 | 3
4k7 | Resistor SMD 0603 | R10, R11, R12 | RES_0603 | RES_0603 | 3
PTS645SM43SMTR92 LFS | Switch | SW1 | SW_PB | SW-PB | 1
CN3801 | LiFePO4 charge IC with integrated MPPT and wide input range (4.5 to 28V) with deeply discharged cell revive | U1 | | CN3801 | 1
HY2112 | LiFePO4 protection IC | U2 | | HY2112 | 1
TPS63000_1 | Buck-Boost Switching Regulator IC Positive Adjustable 1.2V 1 Output 1.6A _Switch_ 10-VFDFN Exposed Pad | U3 | 10-VFDFN | TPS63000_1 | 1
W25Q16JVUXIQ | 16M-BIT SERIAL FLASH MEMORY WITH DUAL/QUAD SPI USON-8 | U4 | USON-8-2X3MM | W25Q16JVUXIQ | 1
ESP32-C3 | Ultra-Low-Power SoC with RISC-V Single-Core CPU Supporting IEEE 802.11b/g/n (2.4 GHz Wi-Fi) and Bluetooth® 5 (LE) | U5 | QFN32-5x5 | ESP32-C3 | 1
SX1280 | Low power LoRa transceiver operating at 2.4GHz with ranging capability | U6 | | SX1280 | 1
ST25DV04K | ST25DO4K NFC module with I2C | U7 | | ST25DV04K | 1
XTAL_2016 | Crystal SMD 4-Pin 2.0x1.6mm | X1 | XTAL_2016 | XTAL_2016 | 1
32.768kHz | Crystal | X2 | SX-3215 | CRYSTAL_1 | 1
52MHz | Crystal | Y1 | XTAL_3225 | Crystal | 1

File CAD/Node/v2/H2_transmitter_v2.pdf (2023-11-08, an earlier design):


Siz e A4 | Numb e r Powe r | R evisio n 1

Da te : 11-08-2 0 2 3 | She et of 1 4
File : D:\fa cultate\. .\1_P o w e r . S c hD o c | Dr awn B y : C ristian Opr e a


C12 | | PC14-OSC32_IN 3

GND

SX-3215 | PH0-OSC_IN 5

PC15-OSC32_OUT 4

PH3/BOOT0 44

NRST 7


Siz e A4 | Numb e r Communicati o n | R evisio n 1

Da te : 11-08-2 0 2 3 | She et of 2 4
File : D:\fa cultate\. .\3_Communic ati o n . S c hD o c | Dr awn B y : C ristian Opr e a


2 GPIOs should be capable of I2C
and digital GPIO; at least one
should have analog functionality

Size A4 | Number Expansion | Revision 1

Date: 11-08-2023 | Sheet of 4 4 Cristian Oprea
File: D:\facultate\..\4_Expansion.SchDoc | Drawn By:


Comment | Description | Designator | Footprint | LibRef | Quantity
100n | Capacitor SMD 0603 | C1, C2, C32, C33 | C0603 | CAP_0603 | 4
Supercapacitor | Supercapacitor | C3 | CAP_POL_8x16x3.5 | Supercapacitor | 1
10uF | Capacitor SMD 0805 | C4 | C0805 | CAP_0805 | 1
10n | Capacitor SMD 0603 | C5, C26, C27 | C0603 | CAP_0603 | 3
4.7u | Capacitor SMD 0603 | C6 | C0603 | CAP_0603 | 1
1uF | Capacitor SMD 0603 | C7, C8, C14 | C0603 | CAP_0603 | 3
100nF | Capacitor SMD 0603 | C9, C10, C15, C16, C17 | C0603 | CAP_0603 | 5
6.8pF | Capacitor SMD 0603 | C11, C12 | C0603 | CAP_0603 | 2
10nF | Capacitor SMD 0603 | C13 | C0603 | CAP_0603 | 1
4.7uF | Capacitor SMD 0603 | C18 | C0603 | CAP_0603 | 1
8pF | Capacitor SMD 0603 | C19, C20 | C0603 | CAP_0603 | 2
22nF | Capacitor SMD 0603 | C21 | C0603 | CAP_0603 | 1
10pF | Capacitor SMD 0603 | C22 | C0603 | CAP_0603 | 1
0.5pF | Capacitor SMD 0603 | C23 | C0603 | CAP_0603 | 1
100pF | Capacitor SMD 0603 | C24 | C0603 | CAP_0603 | 1
TBD | Capacitor SMD 0805 | C25, C31 | C0805 | CAP_0603 | 2
0.8pF | Capacitor SMD 0805 | C28 | C0603 | CAP_0805 | 1
1.2pF | Capacitor SMD 0603 | C29, C30 | C0603 | CAP_0603 | 2
470n | Capacitor SMD 0603 | C34 | C0603 | CAP_0603 | 1
CR2032 | CR2032 Coin Cell Battery Holder | J1 | BAT_CR2032-BS-6-1 | CR2032-BS-6-1 | 1
Plugin Terminal | Screw terminal or plug terminal for power | J2 | 2.54_pluggable_termi nal | Power_Connector | 1
Header 6X2 | Header, 12-Pin, Dual row | J3 | HEADER_6x2_2.54 | Header 6x2 | 1
SWD connector | Single Wire Debug connector with UART _TX pin | J4 | HEADER_2x2_2.54 | SWD connector | 1
SMA_EDGE_CONN | RF Connector SMA Female 50 Ohms 18 GHz PCB Edge Mount | J5 | CON_SMA-EDGE-S | CON-SMA-EDGE-S | 1
EDGE_CONNECTOR | Connector for sensor modules | J6, J7, J8, J9, J10 | 2.54mm_edge_connec tor | edge_connector | 5
JUMPER | | JP1, JP2 | HEADER_1x2_2.54 | JUMPER | 2
22u | Inductor SMD 1008 | L1 | IND_3.2_4 | IND_1008 | 1
3nH | Inductor SMD 0603 | L2 | R0603 | IND_0603 | 1
2.5nH | Inductor SMD 0603 | L3 | R0603 | IND_0603 | 1
15u | Inductor SMD 0603 | L4 | IND_3.2_4 | IND_0603 | 1
4.7M | Resistor SMD 0603 | R1 | R0603 | RES_0603 | 1
18M | Resistor SMD 0603 | R2 | R0603 | RES_0603 | 1
221k | Resistor SMD 0603 | R3 | R0603 | RES_0603 | 1
150k | Resistor SMD 0603 | R4 | R0603 | RES_0603 | 1
5.49M | Resistor SMD 0603 | R5 | R0603 | RES_0603 | 1
5.62M | Resistor SMD 0603 | R6 | R0603 | RES_0603 | 1
6.04M | Resistor SMD 0603 | R7 | R0603 | RES_0603 | 1
5.9M | Resistor SMD 0603 | R8 | R0603 | RES_0603 | 1
4.53M | Resistor SMD 0603 | R9 | R0603 | RES_0603 | 1
4.32M | Resistor SMD 0603 | R10 | R0603 | RES_0603 | 1
3.92M | Resistor SMD 0603 | R11 | R0603 | RES_0603 | 1
100k | Resistor SMD 0603 | R12 | R0603 | RES_0603 | 1
4.12M | Resistor SMD 0603 | R13 | R0603 | RES_0603 | 1
1k | Resistor SMD 0603 | R14 | R0603 | RES_0603 | 1
PTS645SM43SMTR92 LFS | Switch | SW1 | SW_SKRPACE010 | SW-PB | 1
ADP5091 | Ultralow Power Energy Harvester PMUs with MPPT and Charge Management and BAckup Supply | U1 | LFCSP-24 | ADP5091 | 1
TPS22919 | 5.5-V, 1.5-A, 90-mΩ load switch with adjustable output discharge | U2, U3 | SC70-6 | TPS22919 | 2
STM32L431 | Ultra-low-power Arm® Cortex®-M4 32-bit MCU+FPU, 100DMIPS, up to 128KB flash, 40KB SRAM(LQFP48) | U4 | QFPN-48 | STM32L431 | 1
SX1280 | Low power LoRa transceiver operating at 2.4GHz with ranging capability | U5 | QFN-24_4x4_0.5 | SX1280 | 1
32.768kHz | Crystal | Y1 | CRYSTAL_SX-3215 | CRYSTAL_1 | 1
8MHz | Crystal | Y2 | CRYSTAL_ECX-32_3.2x2.5x0.8 -duplicate | Crystal | 1
52MHz | Crystal | Y3 | CRYSTAL_2016_4P | Crystal | 1

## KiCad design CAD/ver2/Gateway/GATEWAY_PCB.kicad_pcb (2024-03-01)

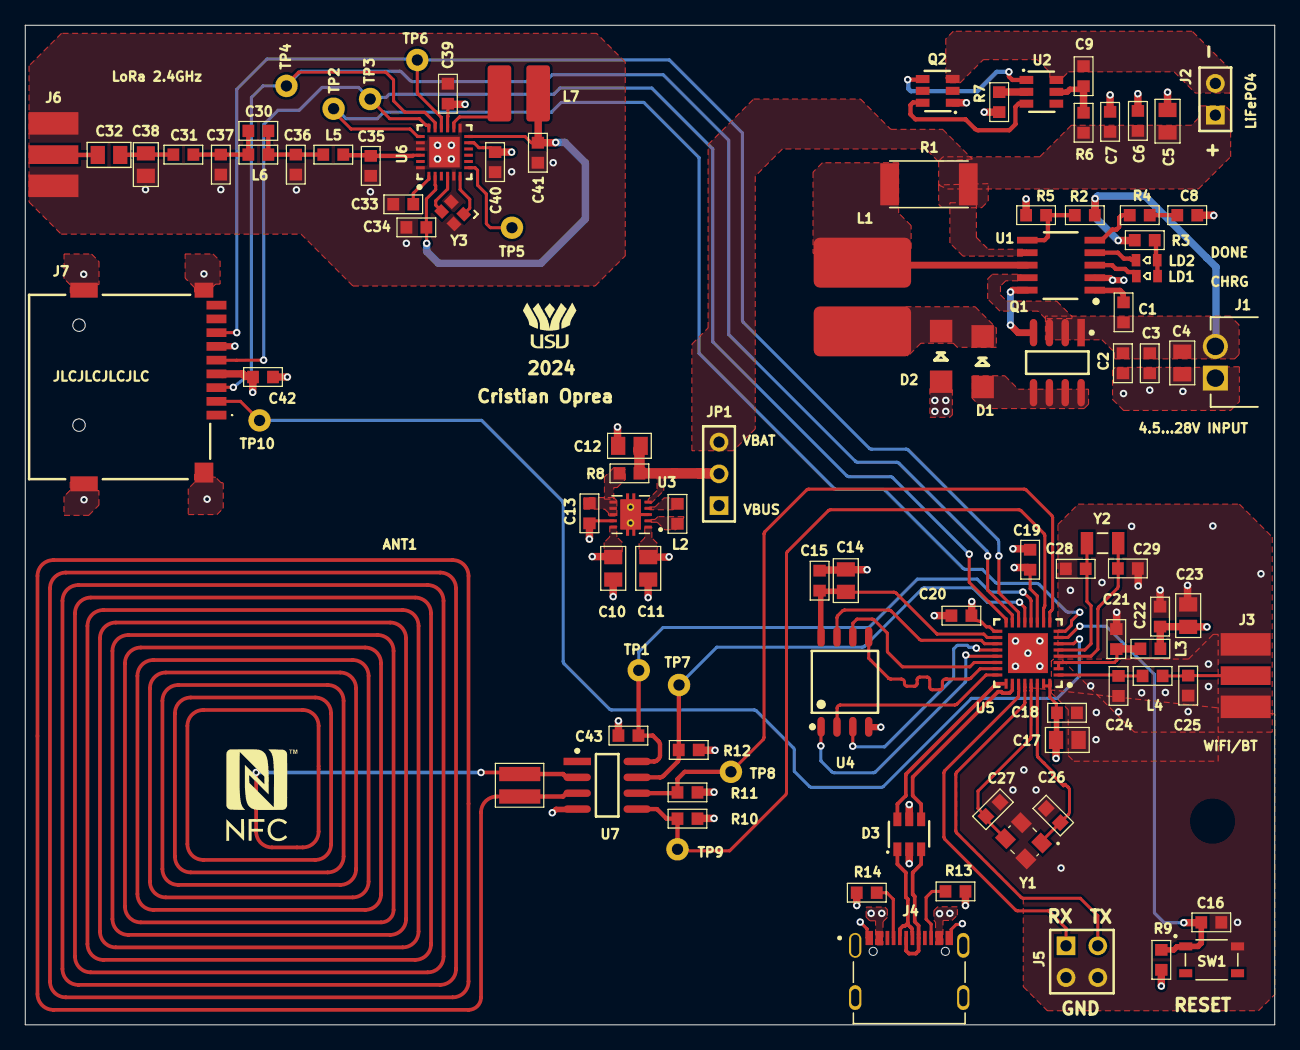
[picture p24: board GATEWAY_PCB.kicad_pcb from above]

Board: 4 copper layers, 100.0 x 80.0 mm, 101 parts (0 on the bottom side), 70 nets.

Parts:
ANT1: NFC_ANTENNA; ANT16
C1, C2, C7, C9, C13, C14, C16, C18, C19, C20, C21, C22, C39, C40, C42, C43: 100nF; C0603
C3, C6: 4.7uF; C0603
C4, C5, C10, C11, C12, C15, C17, C23: 10uF; C0805
C8: 220nF; C0603
C24, C25: 3p3; C0603
C26, C27, C28, C29: 16pF; C0603
C30: 0.5pF; C0603
C31: 100pF; C0603
C32, C38: TBD; C0805
C33, C34: 10nF; C0603
C35: 0.8pF; C0603
C36, C37: 1.2pF; C0603
C41: 470nF; C0603
D1, D2: SS34; DO-214AC
D3: USBLC6-2SC6; SOT23-6
J1: PLUGIN_TERMINAL; 2.54_PLUGGABLE_TERMINAL
J2: PLUGIN_TERMINAL; HEADER_1X2_2.54
J3: SMA; CON_SMA-EDGE-S
J4: USB4145-03-0170-C; VALCON_CSP-USC16-TR
J5: Header1x4; HEADER_2X2_2.54
J6: SMA_EDGE_CONN; CON_SMA-EDGE-S
J7: uSD_CARD_HOLDER; TF115BCP9
JP1: JUMPER_3PIN; HEADER_1X3_2.54
L1: 47uH; IND_5_7
L2: 2.2uH; L0603
L3, L4: 2.2nH; L0603
L5: 3nH; L0603
L6: 2.5nH; L0603
L7: 15uH; IND_3.2_4
LD1: LED_RED; LED0603RD
LD2: LED_GREEN; LED0603GR
Q1: FDS4435; SOIC-SN8_N
Q2: FS8205; SOT23-6
R1: 0R250; R2512
R2: 27k; R0603
R3: 1k5; R0603
R4: 120R; R0603
R5: 3k; R0603
R6, R8: 100R; R0603
R7: 2k; R0603
R9, R10, R11, R12, R13, R14: 5.1k; R0603
SW1: PTS645SM43SMTR92 LFS; SW_SKRPACE010
TP1, TP2, TP3, TP4, TP5, TP6, TP7, TP8, TP9, TP10: TP_NOBOM; TEST_PAD_THD
U1: CN3801; SSOP-10
U2: HY2112; SOT23-6
U3: TPS63000; VREG_V62/16624-01YE
U4: W25Q16JVUXIQ; SOIC-8N_208mil
U5: ESP32-C3; QFN-32-5X5X0.85MM
U6: SX1280; QFN-24_4X4_0.5
U7: ST25DV04K; SOIC-SN8_N
Y1: 40 MHz; CRYSTAL_ECX-32_3.2X2.5X0.8 - DUPLICATE
Y2: 32.768kHz; CRYSTAL_SX-3215
Y3: 52MHz; CRYSTAL_2016_4P

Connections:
3V3: C10.2, C11.2, C17.2, C18.2, C19.2, C20.2, C22.2, C23.2, C39.2, C40.2, C42.2, J7.4, L3.2, R9.2, R10.2, R11.2, R12.2, U3.1, U3.10, U5.11, U5.17, U5.31, U5.32, U6.11, U6.15
3V3_RF: C21.2, L3.1, U5.2, U5.3
CHIP_EN: C16.2, R9.1, SW1.1, U5.7
GND: C2.1, C3.1, C4.1, C5.1, C6.1, C7.1, C8.1, C10.1, C11.1, C12.1, C13.1, C14.1, C15.1, C16.1, C17.1, C18.1, C19.1, C20.1, C21.1, C22.1, C23.1, C24.1, C25.1, C26.1, C27.1, C28.1, C29.1, C33.1, C34.1, C35.1, C36.1, C37.1, C38.1, C39.1, C40.1, C41.1, C42.1, C43.1, D2.1, D3.2, J1.1, J3.2, J4.A1, J4.A12, J4.B1, J4.B12, J5.3, J5.4, J6.2, J7.6, J7.10, J7.11, J7.12, J7.13, Q2.1, R5.1, R7.1, R13.1, R14.1, SW1.2, U1.2, U3.3, U3.9, U3.11, U4.4, U5.33, U6.5, U6.13, U6.20, U6.21, U6.24, U6.25, U7.4, Y1.2, Y1.4, Y3.2, Y3.4
MCU_USB_D_N: D3.6, U5.25
MCU_USB_D_P: D3.4, U5.26
NetANT1_1: ANT1.1, U7.2
NetANT1_2: ANT1.2, U7.3
NetC1_1: C1.1, U1.1
NetC8_2: C8.2, R4.1
NetC9_2: C9.2, R6.2, U2.5
NetC12_2: C12.2, JP1.2, R8.2, U3.5
NetC13_2: C13.2, R8.1, U3.6, U3.7, U3.8
NetC24_2: C24.2, L4.1, U5.1
NetC25_2: C25.2, J3.1, L4.2
NetC26_2: C26.2, U5.30, Y1.1
NetC27_2: C27.2, U5.29, Y1.3
NetC28_2: C28.2, U5.5, Y2.2
NetC29_2: C29.2, U5.4, Y2.1
NetC30_1: C30.1, C31.2, C37.2, L6.2
NetC30_2: C30.2, C36.2, L5.2, L6.1
NetC31_1: C31.1, C32.2, C38.2
NetC32_1: C32.1, J6.1
NetC33_2: C33.2, U6.1
NetC34_2: C34.2, C41.2, L7.1, U6.2, U6.12
NetC35_2: C35.2, L5.1, U6.22
NetC43_2: C43.2, TP1.1, U5.12, U7.8
NetD1_1: D1.1, Q1.5, Q1.6, Q1.7, Q1.8
NetD1_2: D1.2, D2.2, L1.1
NetJ4_A5: J4.A5, R14.2
NetJ4_B5: J4.B5, R13.2
NetJ7_2: J7.2, TP10.1, U5.6
NetJ7_3: J7.3, TP4.1, U5.15, U6.17
NetJ7_5: J7.5, TP3.1, U5.16, U6.18
NetJ7_7: J7.7, TP6.1, U5.14, U6.16
NetL1_2: L1.2, R1.1, U1.8
NetL2_1: L2.1, U3.4
NetL2_2: L2.2, U3.2
NetL7_2: L7.2, U6.14
NetLD1_1: LD1.1, LD2.1, R3.1
NetLD1_2: LD1.2, U1.3
NetLD2_2: LD2.2, U1.4
NetQ1_4: Q1.4, U1.10
NetQ2_4: Q2.4, U2.1
NetQ2_6: Q2.6, U2.3
NetR2_1: R2.1, R5.2, U1.6
NetR4_2: R4.2, U1.5
NetR7_2: R7.2, U2.2
NetR10_1: R10.1, TP9.1, U5.10, U7.5
NetR11_1: R11.1, TP8.1, U5.9, U7.6
NetR12_1: R12.1, TP7.1, U5.13, U7.7
NetTP2_1: TP2.1, U5.8, U6.19
NetTP5_1: TP5.1, U6.7
NetU6_4: U6.4, Y3.3
NetU6_6: U6.6, Y3.1
SPI_CLK: U4.6, U5.22
SPI_DI: U4.5, U5.23
SPI_DO: U4.2, U5.24
SPI_NCS: U4.1, U5.21
SPI_NHOLD: U4.7, U5.19
SPI_NWP: U4.3, U5.20
UART0_RXD: J5.1, U5.27
UART0_TXD: J5.2, U5.28
USB_D_N: D3.1, J4.A7, J4.B7
USB_D_P: D3.3, J4.A6, J4.B6
VBAT+: C5.2, C6.2, C7.2, J2.1, JP1.3, R1.2, R6.1, U1.7
VBAT-: C9.1, J2.2, Q2.3, U2.6
VBUS: D3.5, J4.A4, J4.A9, J4.B4, J4.B9, JP1.1
VDD_SPI: C14.2, C15.2, U4.8, U5.18
VIN: C1.2, C2.2, C3.2, C4.2, J1.2, Q1.1, Q1.2, Q1.3, R2.2, R3.2, U1.9

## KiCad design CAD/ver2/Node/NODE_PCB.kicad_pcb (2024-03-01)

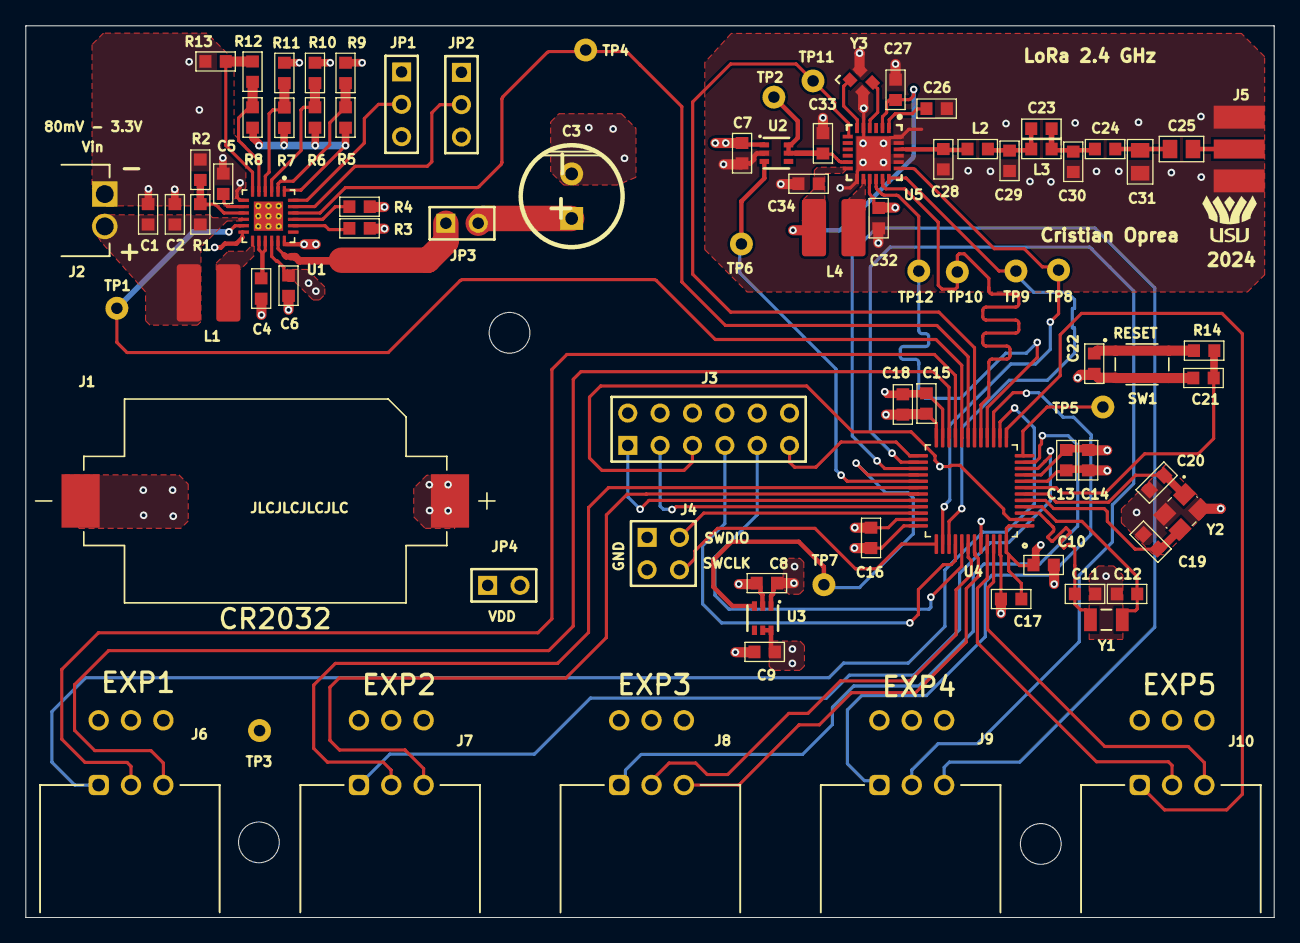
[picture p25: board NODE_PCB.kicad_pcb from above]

Board: 4 copper layers, 98.0 x 70.0 mm, 87 parts (0 on the bottom side), 72 nets.

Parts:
C1, C4: 10uF; C0603
C2, C9, C10, C15, C16, C17, C32, C33: 100nF; C0603
C3: Supercapacitor; CAP_POL_8X16X3.5
C5, C13, C21, C26, C27: 10nF; C0603
C6, C18: 4.7uF; C0603
C7, C8, C14: 1uF; C0603
C11, C12, C19, C20, C22: 16pF; C0603
C23: 0.5pF; C0603
C24: 100pF; C0603
C25, C31: TBD; C0805
C28: 0.8pF; C0603
C29, C30: 1.2pF; C0603
C34: 470nF; C0603
J1: CR2032; BAT_CR2032-BS-6-1
J2: Plugin Terminal; 2.54_PLUGGABLE_TERMINAL
J3: Header 6X2; HEADER_6X2_2.54
J4: SWD connector; HEADER_2X2_2.54
J5: SMA_EDGE_CONN; CON_SMA-EDGE-S
J6, J7, J8, J9, J10: EDGE_CONNECTOR; 2.54MM_EDGE_CONNECTOR
JP1, JP2: JUMPER_3PIN; HEADER_1x3_2.54
JP3, JP4: JUMPER; HEADER_1X2_2.54
L1: 22uH; IND_3.2_4
L2: 3nH; R0603
L3: 2.5nH; R0603
L4: 15uH; IND_3.2_4
R1: 4.7M; R0603
R2: 18M; R0603
R3: 221k; R0603
R4: 150k; R0603
R5: 5.49M; R0603
R6, R8: 5.9M; R0603
R7: 6.04M; R0603
R9: 4.53M; R0603
R10, R13: 4.12M; R0603
R11: 3.92M; R0603
R12: 100k; R0603
R14: 1.5k; R0603
SW1: PTS645SM43SMTR92 LFS; SW_SKRPACE010
TP1, TP2, TP3, TP4, TP5, TP6, TP7, TP8, TP9, TP10, TP11, TP12: TP_NOBOM; TEST_PAD_THD
U1: ADP5091; LFCSP-24
U2, U3: TPS22919; SC70-6
U4: STM32L431; QFPN-48
U5: SX1280; QFN-24_4X4_0.5
Y1: 32.768kHz; CRYSTAL_SX-3215
Y2: 8MHz; CRYSTAL_ECX-32_3.2X2.5X0.8 - DUPLICATE
Y3: 52MHz; CRYSTAL_2016_4P

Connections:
GND: C1.1, C2.1, C3.2, C4.2, C5.1, C6.1, C7.1, C8.1, C9.1, C10.1, C11.1, C12.1, C13.1, C14.1, C15.1, C16.1, C17.1, C18.1, C19.1, C20.1, C21.1, C22.1, C26.1, C27.1, C28.1, C29.1, C30.1, C31.1, C32.1, C33.1, C34.1, J1.N, J2.1, J3.2, J3.4, J3.6, J3.8, J3.10, J3.12, J4.1, J4.3, J5.2, J6.5, J6.6, J7.5, J7.6, J8.5, J8.6, J9.5, J9.6, J10.5, J10.6, JP1.3, JP2.3, R2.1, R3.1, R4.1, R9.1, R10.1, R11.1, R13.1, SW1.3, SW1.4, U1.7, U1.12, U2.2, U3.2, U4.8, U4.23, U4.35, U4.44, U4.47, U5.5, U5.13, U5.20, U5.21, U5.23, U5.24, U5.25, Y2.2, Y2.4, Y3.2, Y3.4
NetC3_1: C3.1, JP3.2
NetC4_1: C4.1, U1.14, U1.15
NetC5_2: C5.2, U1.8
NetC6_2: C6.2, JP4.1, U1.16
NetC11_2: C11.2, U4.3, Y1.2
NetC12_2: C12.2, U4.4, Y1.1
NetC19_2: C19.2, U4.5, Y2.3
NetC20_2: C20.2, U4.6, Y2.1
NetC21_2: C21.2, R14.1, U4.7
NetC22_2: C22.2, R14.2, SW1.1, SW1.2
NetC23_1: C23.1, C24.2, C30.2, L3.2
NetC23_2: C23.2, C29.2, L2.2, L3.1
NetC24_1: C24.1, C25.2, C31.2
NetC25_1: C25.1, J5.1
NetC26_2: C26.2, U5.1
NetC27_2: C27.2, C34.2, L4.1, U5.2, U5.12
NetC28_2: C28.2, L2.1, U5.22
NetJ1_P: J1.P, U1.18
NetJ6_1: J6.1, U4.14
NetJ6_2: J6.2, U4.21
NetJ6_3: J6.3, U4.22
NetJ7_1: J7.1, U4.10
NetJ7_2: J7.2, U4.30
NetJ7_3: J7.3, U4.31
NetJ8_1: J8.1, U4.11
NetJ8_2: J8.2, U4.42
NetJ8_3: J8.3, U4.43
NetJ9_1: J9.1, U4.15
NetJ9_2: J9.2, U4.26
NetJ9_3: J9.3, U4.27
NetJ10_1: J10.1, U4.13
NetJ10_2: J10.2, U4.45
NetJ10_3: J10.3, U4.46
NetJP3_1: JP3.1, U1.17
NetL1_1: L1.1, U1.13
NetL4_2: L4.2, U5.14
NetR1_1: R1.1, R2.2, U1.9
NetR3_2: R3.2, U1.20
NetR4_2: R4.2, U1.21
NetR5_1: R5.1, R9.2, U1.2
NetR5_2: R5.2, R6.2, R7.2, R8.2, U1.1
NetR6_1: R6.1, R10.2, U1.3
NetR7_1: R7.1, R11.2, U1.4
NetR8_1: R8.1, R12.2, U1.5
NetR12_1: R12.1, R13.2, U1.6
NetTP1_1: TP1.1, U1.11, U4.20
NetTP4_1: TP4.1, U1.22, U4.19
NetTP6_1: TP6.1, U2.3, U4.29
NetTP7_1: TP7.1, U3.3, U4.28
NetTP8_1: TP8.1, U4.38, U5.19
NetTP9_1: TP9.1, U4.39, U5.18
NetTP10_1: TP10.1, U4.17, U5.17
NetTP11_1: TP11.1, U4.18, U5.7
NetTP12_1: TP12.1, U4.16, U5.16
NetU5_4: U5.4, Y3.3
NetU5_6: U5.6, Y3.1
PA11: J3.1, U4.32
PA12: J3.3, U4.33
PB4: J3.7, U4.40
PB5: J3.9, U4.41
PB12: J3.11, U4.25
PC13: J3.5, U4.2
REG_D0: JP1.2, U1.24
REG_D1: JP2.2, U1.23
SWCLK: J4.4, U4.37
SWDIO: J4.2, U4.34
UART_TX: TP5.1, U4.12
VDD: C7.2, C8.2, C10.2, C13.2, C14.2, C15.2, C16.2, C17.2, C18.2, JP1.1, JP2.1, JP4.2, U2.1, U3.1, U4.1, U4.9, U4.24, U4.36, U4.48
VDD_COM: C32.2, C33.2, TP2.1, U2.5, U2.6, U5.11, U5.15
VDD_SENS: C9.2, J6.4, J7.4, J8.4, J9.4, J10.4, TP3.1, U3.5, U3.6
VIN: C1.2, C2.2, J2.2, L1.2, R1.2, U1.10

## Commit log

2023-11-08 Create Gateway
    Gateway PCB
2023-11-09 Create Enclosure
2024-01-08 Create app development folder
    App development using react native and expo mainly for android devices (easier implementation for NFC and BLE)
2024-01-08 Create Monopole antenna
